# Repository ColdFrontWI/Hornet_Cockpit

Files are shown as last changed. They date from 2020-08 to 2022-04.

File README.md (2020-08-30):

# Eric's Hornet Cockpit file repository

A bunch of files I've created as part of designing and building a home cockpit for the F/A-18C.  Used in DCS playing in VR.

Folders here are:
* [**Pictures**](Pictures) is a good place to start as it includes writeups at several points in the history of
the build.  Part of that is a lot of pictures of the finished panel as well as the assembly process.
* [**DXF files**](DXF%20Files) contains CAD drawings that I used for the design of the side consoles and front panel, as well as
drawings used to construct the enclosures.  I created these in QCAD, but the drawings are in DXF format, so they should be
editable by most CAD tools.
* [**STL files**](STL%20Files) are the designs I created and used to 3D print various cockpit knobs and switches.  Having controls with the
right shape make things *much* easier in VR.  I'm not including gcode at this point as every printer is different, so you'll have to slice
these yourself.  I designed all of these in Fusion360, but I'm not including those files, mostly because Fusion360 is cloud-based, and it's
a pain to extract them to your machine.
* [**Arduino Code**](Arduino%20Code) are the programs I have written to drive the Arduino boards I use in my build.  While this is very specific
to my use cases, if you are new to Arduino coding this may provide some ideas.  [The Readme](Arduino%20Code/Readme.md) also includes
info about which boards work and a couple of code libraries that are likely to be needed.
* [**DCS lua code**](DCS%20lua%20code) are my customizations to the "default.lua" file that defines how cockpit controls work.  With some
modifications to the .lua code it is possible, for example, to make toggle switches send an action when turned OFF in addition to
when turned ON.  [The Readme](DCS%20lua%20code/Readme.md) explains the location of the files within the DCS install and provides guidance
on how to incorporate into DCS.
* [**Doc**](Doc) is NOT full documentation, but just a collection of files and links that I have collected and created for reference
along the way.

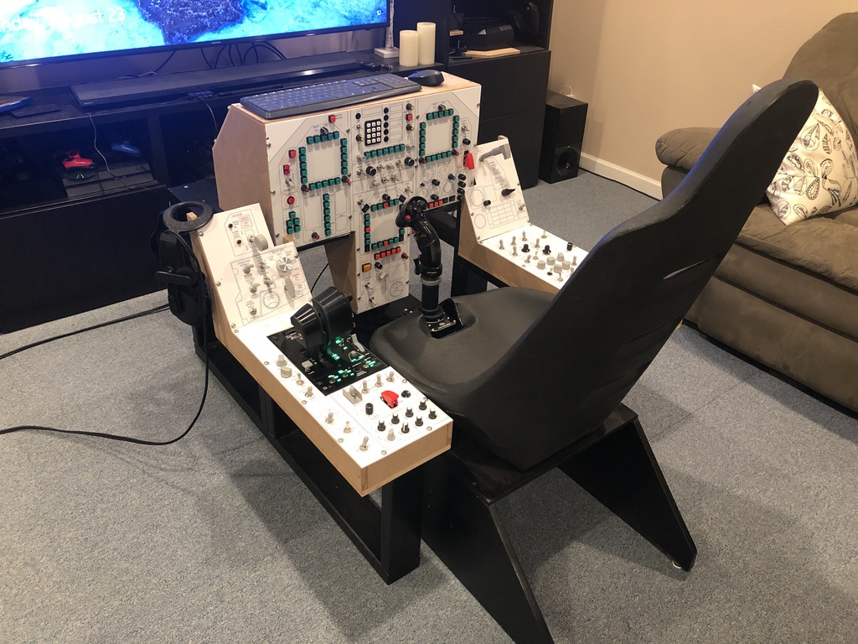
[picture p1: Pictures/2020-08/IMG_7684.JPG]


## License information

Shield: [][cc-by-sa]

This work is licensed under a
[Creative Commons Attribution-ShareAlike 4.0 International License][cc-by-sa].

[][cc-by-sa]

[cc-by-sa]: http://creativecommons.org/licenses/by-sa/4.0/
[cc-by-sa-image]: https://licensebuttons.net/l/by-sa/4.0/88x31.png
[cc-by-sa-shield]: https://img.shields.io/badge/License-CC%20BY--SA%204.0-lightgrey.svg

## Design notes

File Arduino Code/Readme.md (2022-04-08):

# Arduino code

When I started, I used the excellent [Leo Bodnar](http://www.leobodnar.com/shop/index.php?main_page=index&cPath=94&zenid=8e73e676aaff458fbce1cb81d2dc268f)
boards for my controls, but going forward I plan to use Arduino.  They provide a bit more flexibility, and
I find the coding fun.  My favorite "get started" resource is
[this video](https://www.youtube.com/watch?v=Z7Sc4MJ8RPM) which explains how to build a box using matrix wiring and
provides a link to [the code that drives it](https://github.com/AM-STUDIO/32-FUNCTION-BUTTON-BOX).  Just note that
if you use any latched switches like toggles in your design you'd want to add diodes to prevent ghosting.

## Which Arduino boards work?

The options may be broader if you plan to use DCSbios, but if you want to treat your Arduino as a USB_HID (like a joystick)
you will need one that uses the ATmega32U4 chip.  This includes the [Micro](https://store.arduino.cc/usa/arduino-micro)
and the [Leonardo](https://store.arduino.cc/usa/leonardo), but I have used
[these knockoff "Pro Micro" boards](https://www.amazon.com/gp/product/B07FXCTVQP/ref=ppx_yo_dt_b_search_asin_title?ie=UTF8&psc=1)
that can be had for <$20 for a pack of three on Amazon.

## Necessary libraries

There are two that I've used:
* [MHeironimus's joystick library](https://github.com/MHeironimus/ArduinoJoystickLibrary) is what allows Windows to see your
Arduino as a joystick.  You can set it up with up to 11 axes and 128 buttons.
* [brianlow's rotary encoder library](https://github.com/brianlow/Rotary) makes using encoders easy.

## My code

There are six  programs here:
* [**Supplemental_Controls.ino**](Supplemental_Controls.ino)
is what I use for the supplemental buttons I added to my cockpit to make things easier
to use in DCS in VR (bottom right of the front instrument panel, see picture).  Not part of the real aircraft, but I use it for things like
VR recenter, labels on/off, NVG goggles on/gain, and kneeboard management.  This also winds up picking up the slack from a few other places
where I didn't have ehough inputs.  This program includes code that reads a button matrix as well as rotary encoders.

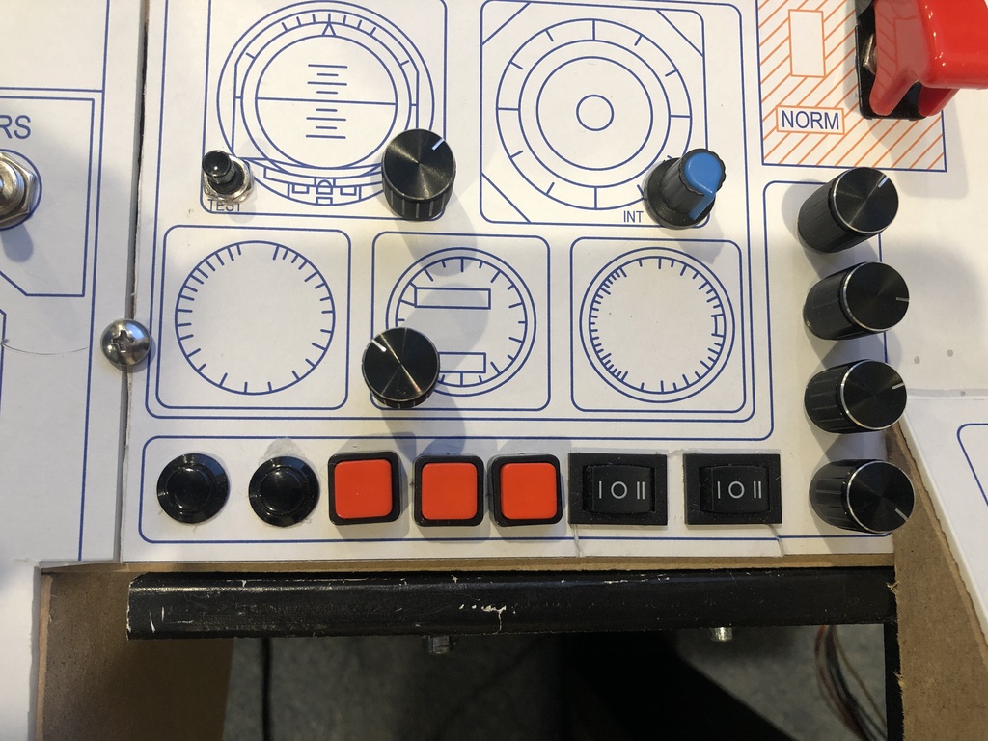
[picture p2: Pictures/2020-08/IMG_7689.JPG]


* [**AMPCD_CMS.ino**](AMPCD_CMS.ino) was created when I added the
APMCD to my build.  It is used for the bottom half of the HUD controls,
the APMCD, and the countermeasures panel.  Again, this includes a switch matrix and also has a couple of analog inputs.  With this program,
I figured out how to send joystick inputs both when a toggle is turned ON as well as when it is turned OFF.  I'm
in the process of editing this to remove some jitter on the analog inputs.

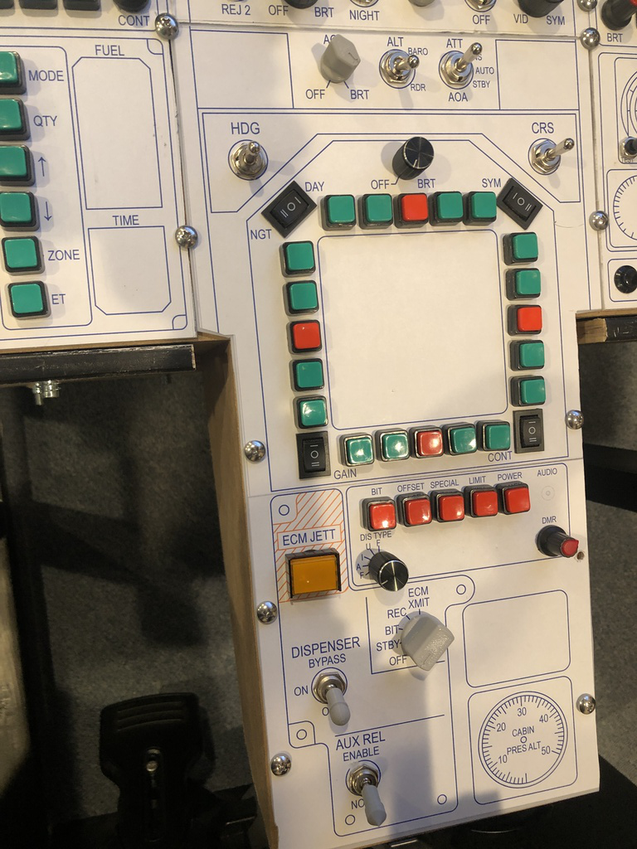
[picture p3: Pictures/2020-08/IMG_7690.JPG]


* Remaining programs control the left and right consoles.  For each console, I have one board for "switches" and one for "knobs" that
includes analog potentiometer inputs as well as rotary encoders.  There's a bit of code starting at line 245 in [Left_Panel_Switches.ino](Left_Panel_Switches.ino) that takes analog input from a potentiometer and converts it to button presses for the left/right
rotation of the hand brake.  (The push/pull is part of the regular button matrix.)  There is similar code in [Right_Panel_Switches.ino](Right_Panel_Switches.ino) for the wing fold handle.

## Next steps

Having replaced the side console Bodnar boards with Arduinos, I'm considering replacing some of the remaining front-panel controls
with them, but this seems a very low priority, as functionally things are working quite well.

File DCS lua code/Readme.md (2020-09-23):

# DCS .lua code

Two categories here:
* The "default\*.lua" files add custom entries in the control setup pages within DCS.  Can use these to make 
ON-OFF toggles work properly.
* "CMDS_ALE47.lua" replaces the default countermeasures programs with something I find more helpful.  Replace
the file found at *~\DCSWorld\Mods\aircraft\FA-18C\Cockpit\Scripts\TEWS\device* with this version.

# Using toggle switches in DCS

Toggle switches present a challenge when building any kind of button box.  While they send an input when you
turn the toggle "on," they don't provide any kind of signal when you turn the toggle "off."  There are some
ways around this:
* You can use ON-ON toggles rather than ON-OFF, but that takes up twice as many inputs on your interface board.
* You can write Arduino code that will send an output not only when a toggle is switched ON, but also when it's switched OFF.
Examples of this type of coding can be found in
[this program](https://github.com/ColdFrontWI/Hornet_Cockpit/blob/master/Arduino%20Code/05_Hornet_AMPCD_CMS.ino) in the
[Arduino Code](https://github.com/ColdFrontWI/Hornet_Cockpit/tree/master/Arduino%20Code) folder.

Fortunately, DCS offers a way to handle this by adding custom controls to an aircraft's control setup menu.  These are
sored in the "default.lua" file.  And some of these types of controls may already be set up:
* In the A-10C, all of the toggles on the TM Warthog throttle work out of the box
* On the Hornet, ED has added appropriate functionality for all of the three-way ON-OFF-ON toggles in the cockpit and a
selection of the two-way ON-OFF toggles.  But many of the ON-OFF toggles will require you to add your own custom controls.

You should be able to add any of the "default - *Aircraft* append.lua" files in this folder, to the "default.lua"
file for the relevant plane, and additional options will show up in the DCS control setup.  Just be sure to take
note of *where* you add the append file.  This is noted in comments of the Hornet version of the file, but I put it
right after the
~~~
join(res.keyCommands,{
~~~
line in default.lua.  Once you edit
default.lua you will see some additional control groups in the setup page (see picture below).
You can then bind them to whichever switch you want.  For reference, the Hornet's default.lua file is located at
*~\DCSWorld\Mods\aircraft\FA-18C\Input\FA-18C\joystick* within the DCS installation.
  
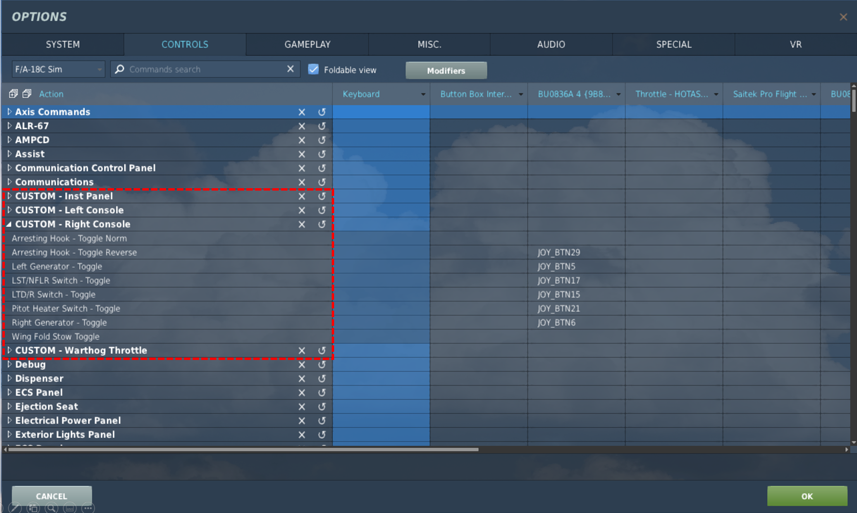
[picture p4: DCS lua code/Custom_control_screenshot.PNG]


## Other notes
* For my cockpit, I set some of the controls up in "reverse" for various reasons.  For example, the toggle I
use for the arresting hook is "on" in the down position rather than up.  If you find some of my custom controls
work in reverse, you can edit it to suit your needs.
* Some switches in the real cockpits are electronically held, so they can automatically be switched off.  Anti-skid
in the Warthog, and LTD/R ARM in the Hornet are examples.  These often have a different value for the "OFF" position
than other switches, so if one is not working you may need to edit.
* Recommend you keep a copy of your "append" file around separate from the main default.lua.  DCS updates occasionally
overwirte default.lua, and if you don't have the append file you'll have to rewrite from scratch.  Ask me how I know ;).

## Other aircraft

Obviously not relevant for the Hornet, but I'm also including the files I set up for the Warthog and the Mustang here.

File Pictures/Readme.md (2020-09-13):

# Pictures

As I have reached major milestones in the build, I have taken some pictures, and have done a brief
writeup of where the project was at that point.

* [**February 2020:**](2020-02/Readme.md) This shows the frame I had built several years ago that all of the
Hornet cockpit mods are attached to.
* [**April 2020:**](2020-04/Readme.md) I had the side consoles built at this point.
* [**May 2020:**](2020-05/Readme.md) Had the side consoles and the original version of the instrument panel built.
This page includes a lot of "behind the scenes" pictures and detail about how each panel was assembled.
* [**August 2020:**](2020-08/Readme.md) Pictures after modifying it to include the AMPCD, as well as adding
bunch of custom-designed, 3D-printed knobs and switches.
* [**September 2020:**](2020-09/Readme.md) A couple of new controls added, a few more 3d printed knobs, and swapping
out the Bodnar boards on the left and right consoles for Arduinos to allow more inputs.



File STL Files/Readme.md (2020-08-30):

# 3D printer files

* [**Knobs**](Knobs): Designed to be used on rotational controllers (potentiometers, rotary encoders, rotary switches).  All fit 6mm splined shafts unless otherwise noted.
* [**Switches**](Switches): Designed to be glued over "standard" bat-style toggle switches.  All have 6mm openings to accomodate the switch.
* [**Other**](Other): Holder for other parts that I've created along the way that may or may not be part of the design.

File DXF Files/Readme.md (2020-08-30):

# DXF Files

Two subfolders here:
* [**Panel**](Panel): This is the detailed switch layout.
* [**Enclosure**](Enclosure): How I built the boxes.

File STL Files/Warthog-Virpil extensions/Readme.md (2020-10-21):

# Warthog / Virpil stick extensions

**Update:** I had a couple of these crack at the male threads after some use when printed using typical settings (2 layer side walls, 20% infill).  So I printed one solid (100% infill), and it's been going strong for a while now.

I had a 75mm extension that I was using with my Virpil WarBRD base and Thrustmaster Hornet grip, but I found that
my setup really needed a 50mm.  I wasn't too keen on spending >$50 (with shipping) and waiting until one was in
stock from Virpil or another supplier, so I decided to design and 3D print my own.  The 50mm design was well-received
when I shared it, and one person requested a different length so I made several between 25 and 100mm.

Note there are three versions of each.  I found that the 36mm female thread on these designs was VERY tight
and difficult to install on my setup, so I created versions where the female threads are 36.5 and 37.0mm.
I think my issue with the 36.0mm may be my printer being slightly out of square, but the 36.5 and 37.0
fit nicely.  You may need to experiment to find out which gives the best fit with your setup.

### 50mm design side-by-side with a 75mm from Virpil

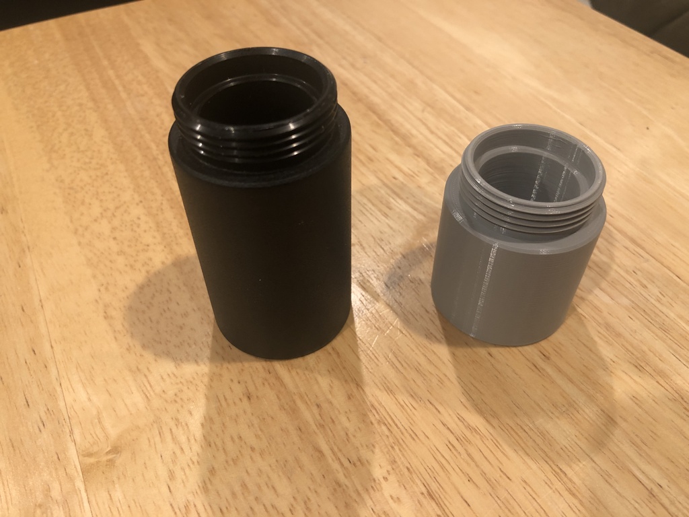
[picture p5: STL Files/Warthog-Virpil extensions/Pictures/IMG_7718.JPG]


### The female threads

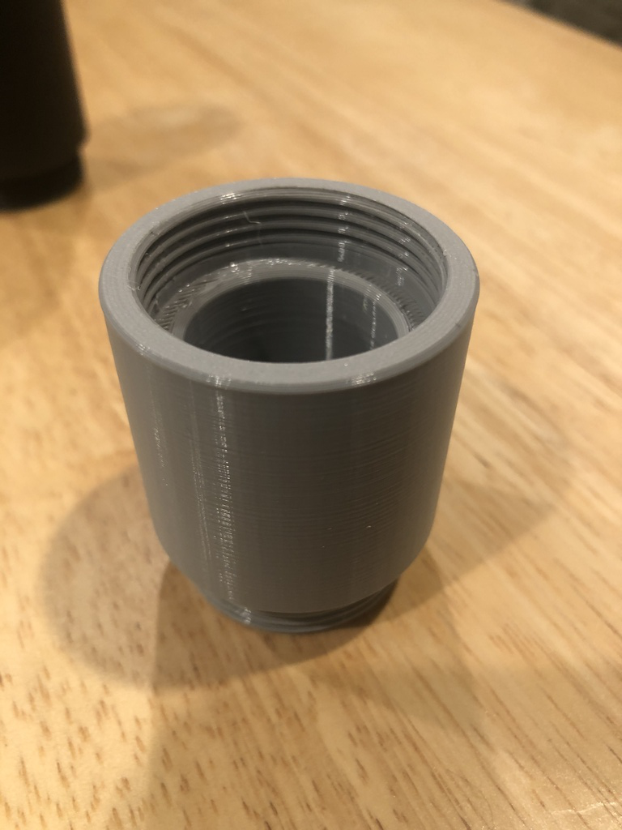
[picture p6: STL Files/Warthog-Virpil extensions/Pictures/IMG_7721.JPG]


### Installed between WarBRD base and TM Hornet grip

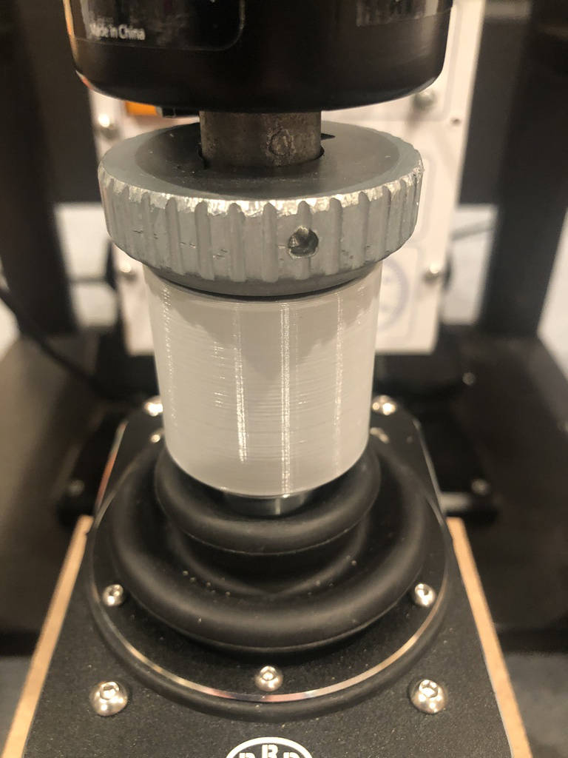
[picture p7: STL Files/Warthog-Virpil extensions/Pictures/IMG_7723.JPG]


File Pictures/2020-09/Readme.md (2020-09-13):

# A few key functional updates

Not many new pictures at this point, but some pretty nice updates.  First, I've added a couple of new
controls.
* I installed [blue73's Jettison Control](https://forums.eagle.ru/showthread.php?t=239718), replacing
the rotary encoder that was there before.  This thing is awesome!
* I changed the hand brake mechanism.  I previously had a pushbutton rotary encoder here, but replaced it with
a push-pull potentiometer, and designed a collar to ensure it moves in a way that's consistent
with the movements in the plane.  This was inspired by [TekCreations use of a push-pull
pot.](https://www.tekcreations.space/f18-landing-panel-part-2/?v=7516fd43adaa)  The STL files
for the collar, the shaft, and the top handle can be found in [the STL files
section.](../../STL%20Files/Other)
* I also swapped the encoders being used for the Radar and INS for proper rotary switches.  Previously it was
way too easy to accidentally bump the INS when using the targeting pod switches.

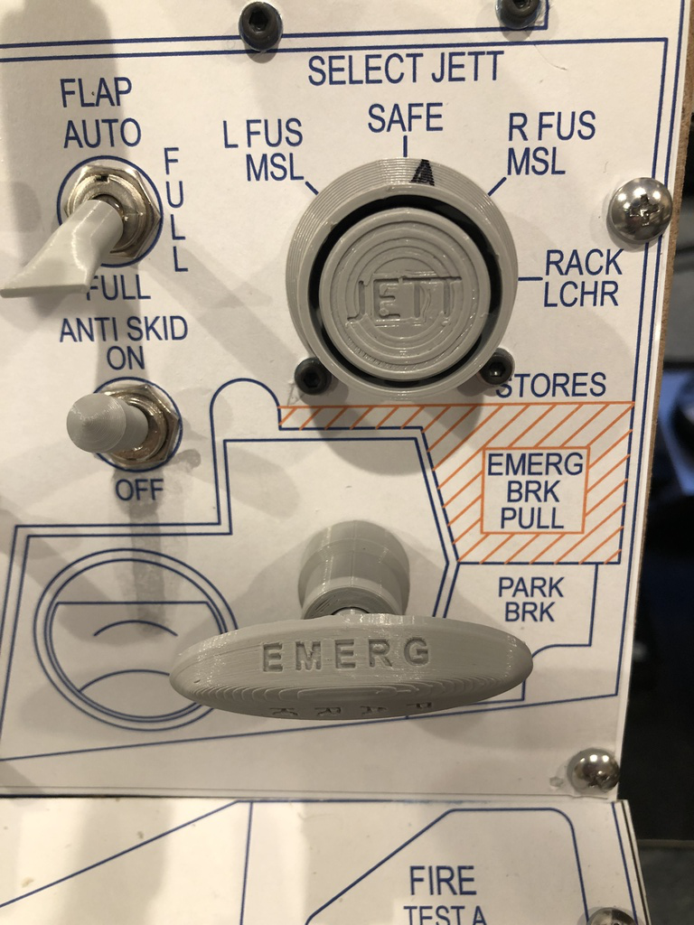
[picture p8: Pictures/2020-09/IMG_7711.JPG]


Those controls were enabled by the biggest change: Swapping out the Bodnar boards on the left
and right consoles for Arduinos.  I wound up using two knock-off Pro Micros in each side (one for switches
and one for analog inpugs and encoders), but this provides a number of nice features:
* **More inputs:** The Bodnar boards I had were limited to 36 digital inputs, and I ran out of inputs
and had to run wires for a couple of things main panel.  This is no longer
necessary.  In the end I have ~50 unique buttons on each side.
* **Send button on both on and off:** I wrote the code so that it sends a joystick button both when a
switch is turned on as well as when it is turned off.  So even though many of my switches are on/off
(e.g. landing gear), it can send a joystick button push in both directions.

I also 3D printed some more knobs including the Bleed Air and Cabin/Suit temp as a rudder trim knob.
For the temp knob, I used a stacked concentric potentiometer...because you know, it's important to
be able to turn those knobs in the cockpit! ;)

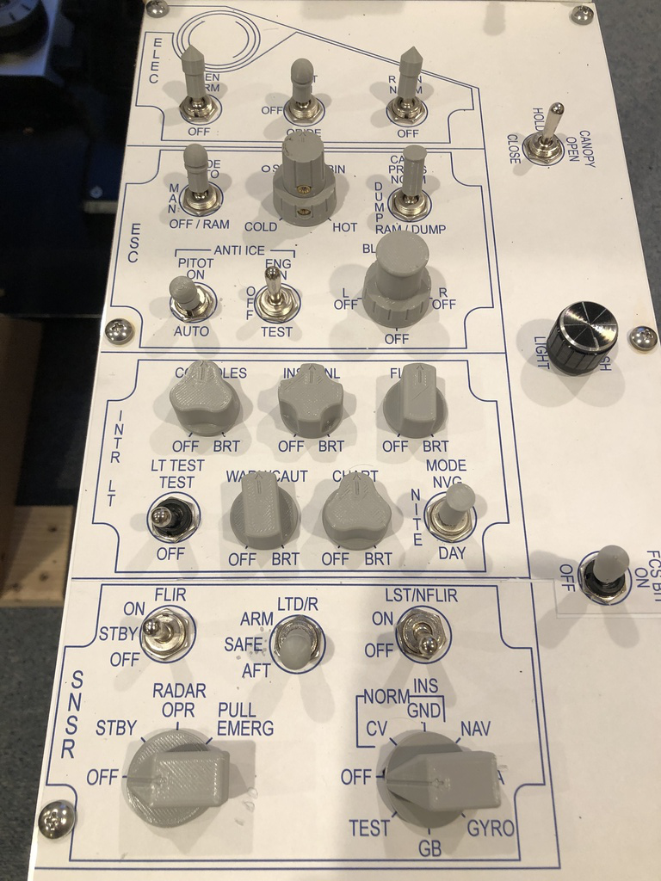
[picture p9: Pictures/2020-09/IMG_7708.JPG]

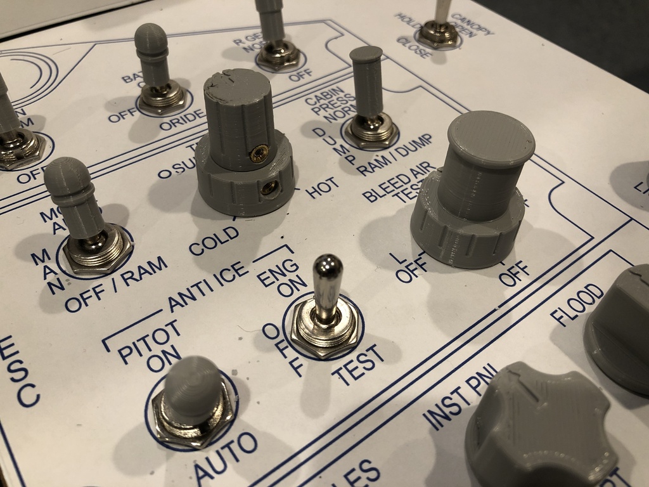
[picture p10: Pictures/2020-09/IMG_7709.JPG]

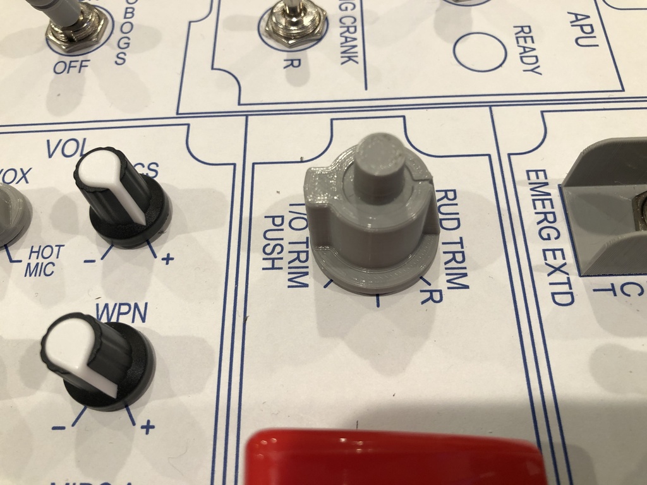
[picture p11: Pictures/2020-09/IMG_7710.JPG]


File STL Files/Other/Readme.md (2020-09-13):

# Other

Random other STL files that I've found or created along the way.  A couple that are here:

* [**Button adapter.stl**](Button%20adapter.stl) and [**Multiselector gear 18t.stl**](Multiselector%20gear%2018t.stl)
are modifications to [blue73's awesome Jettison Select Knob](https://forums.eagle.ru/showthread.php?t=239718)
that allow me to use parts I had on hand including the pushbutton and rotary.  I [posted these to the ED
forums](https://forums.eagle.ru/showpost.php?p=4471487&postcount=58).
* [**Panel - lower LG.stl**](Panel%20-%20lower%20LG.stl) is something I created as a quick test to see if I
could 3D print overlays for my panel to give it a bit more depth.
* When used in conjunction with a push-pull potentiometer, the **"Hand brake"** files create a mechanism
which mirrors the parking / emergency brake in the Hornet.

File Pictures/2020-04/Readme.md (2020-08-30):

# The side consoles

By April, 2020 I had the two side consoles built.  The left side was designed to fit a Warthog throttle.  Also, I don't know if this
is reality, but based on the time I spent sitting in the Hornet DCS cockpit in VR I designed it so the left vertical panel (gear,
etc.) is closer to the pilot than the right side vertical panel (wing fold, arresting hook, etc.), so I built it that way.

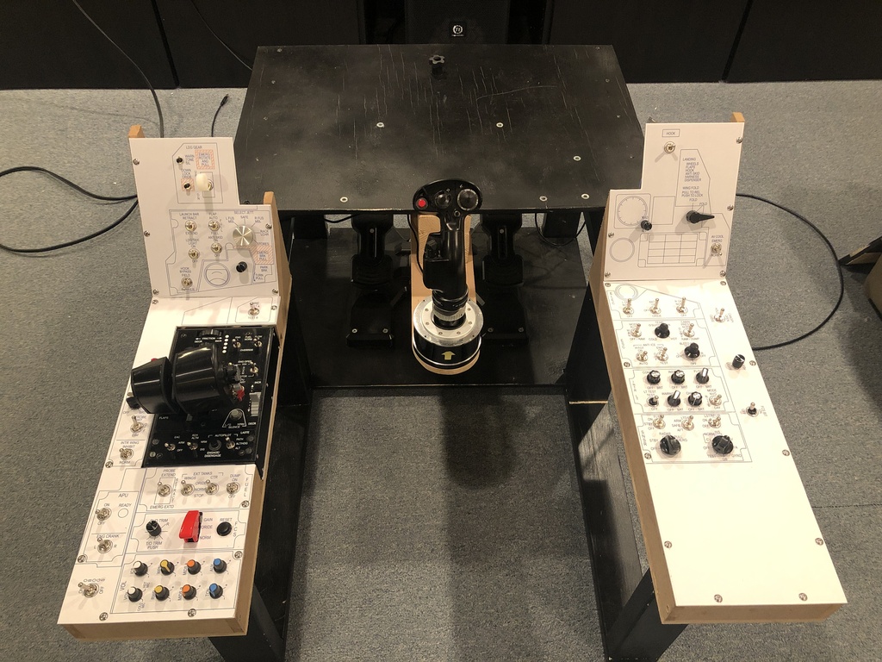
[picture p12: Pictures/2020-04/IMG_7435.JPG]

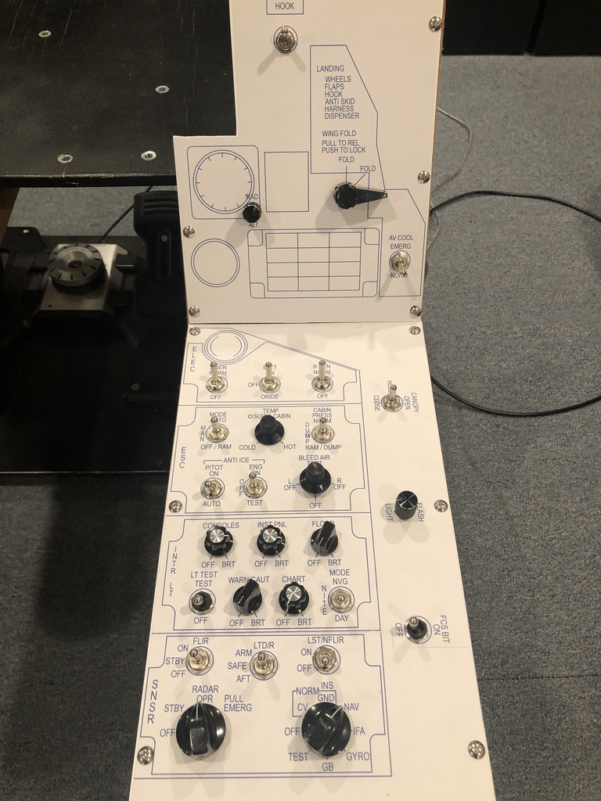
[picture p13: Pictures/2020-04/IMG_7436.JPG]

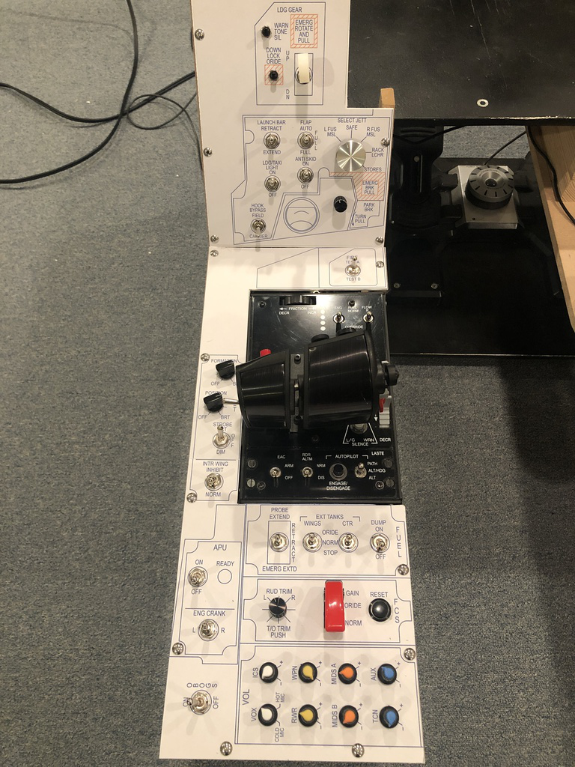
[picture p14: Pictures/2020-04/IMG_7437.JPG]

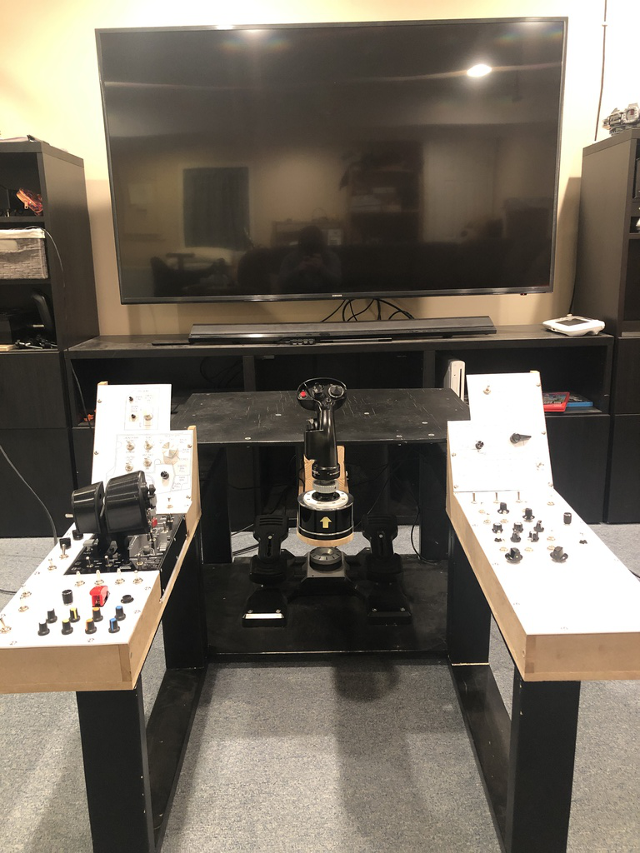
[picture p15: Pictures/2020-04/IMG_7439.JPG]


And as of now it still fits neatly in the corner.

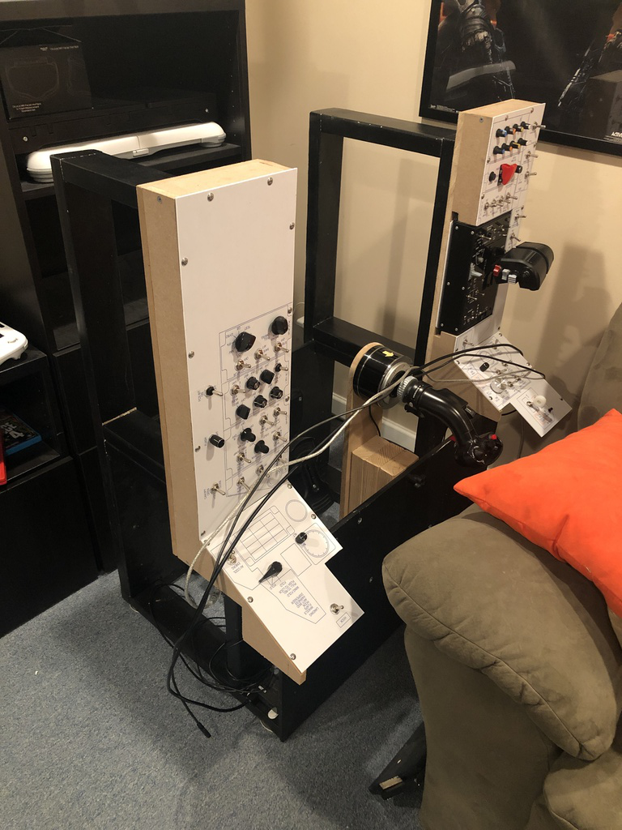
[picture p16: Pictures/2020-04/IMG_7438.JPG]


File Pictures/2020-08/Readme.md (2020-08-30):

# An AMPCD and some fancy knobs

I was really enjoying the design as it existed, but I did find a couple of problems that made it a challenging in VR:
* Some switches and knobs were hard to identify.  I had bought a few knobs that kind of mirrored the shapes in the actual cockpit,
but some were impossible to find.  I also had no way to differentiate toggles, which meant a lot of counting by feel to figure
out which switch I needed to use.
* I got so used to using my panels that I would often reach for the OSBs on the AMPCD, but...I didn't have an AMPCD!  So I would then have
to feel around for my mouse to work with the AMPCD.

## Knobs and switches

To help with identification of controls in VR, I picked up a [Creality Ender 3 Pro 3D printer](https://www.amazon.com/gp/product/B07K3SZBHJ)
and designed a bunch of custom [knobs](../../STL%20Files/Knobs) and [switch caps](../../STL%20Files/Switches).  There is a bit
more detailed information on the designs in the readme files in those locations.

### Knobs

A few custom shapes for various potentiometer and rotary switches in the cockpit, including the parking brake
handle.  For the most part I have made these to fit over splined 6mm shafts.  All of the designs are over in
the [STL Files section](../../STL%20Files/Knobs).  I have made a few more since the pictures below.

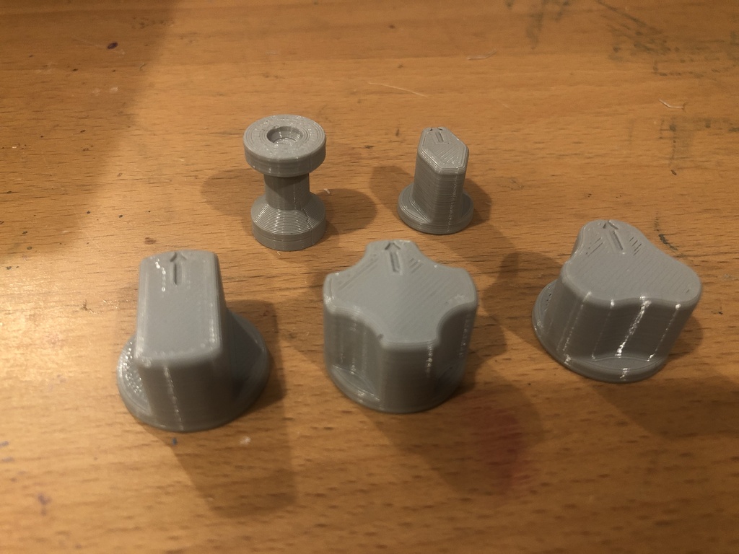
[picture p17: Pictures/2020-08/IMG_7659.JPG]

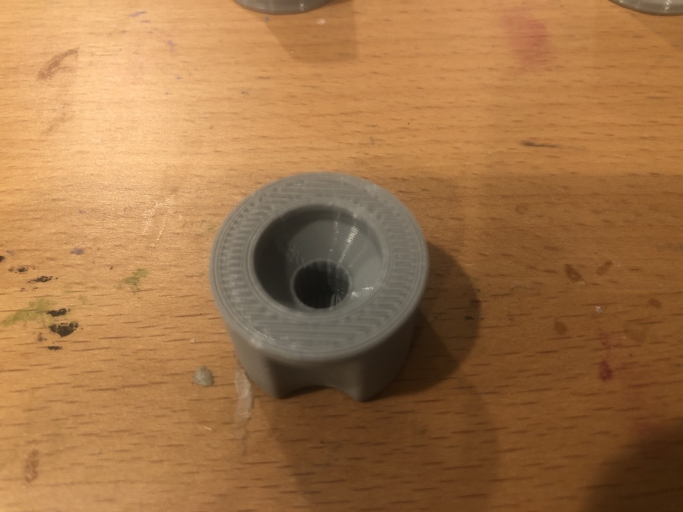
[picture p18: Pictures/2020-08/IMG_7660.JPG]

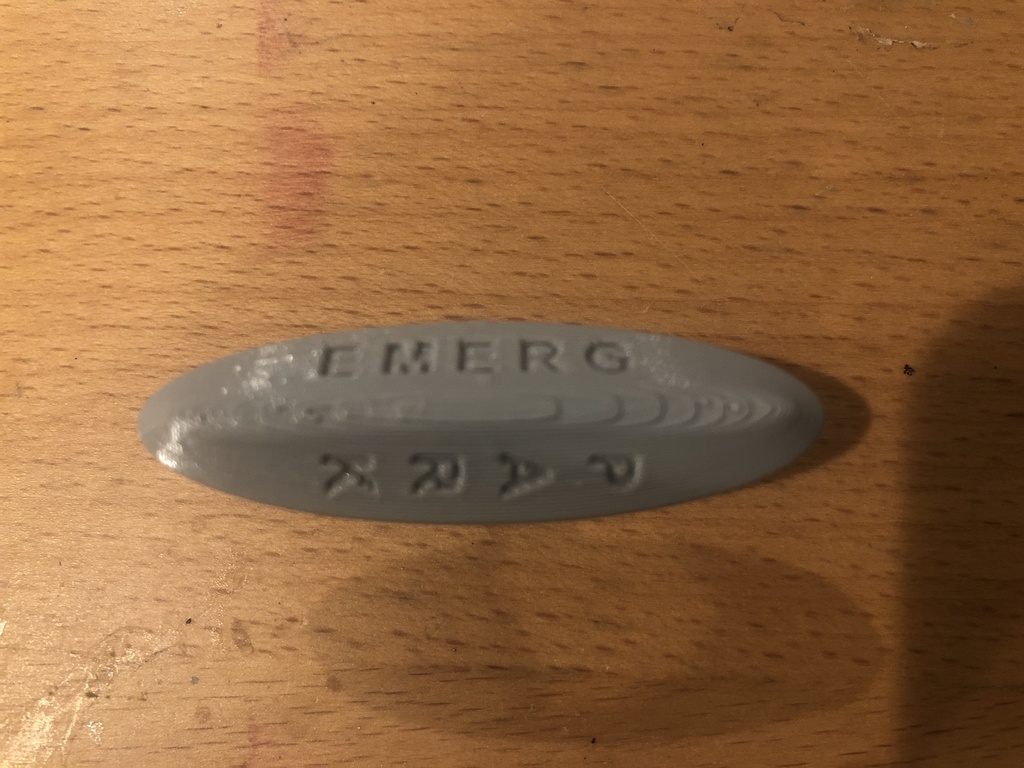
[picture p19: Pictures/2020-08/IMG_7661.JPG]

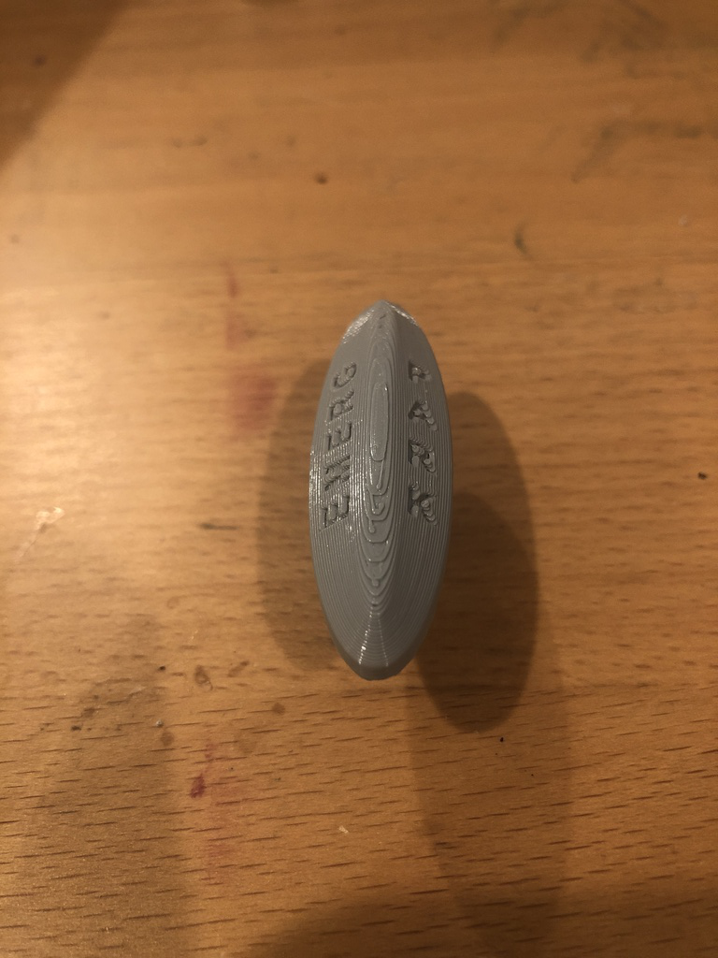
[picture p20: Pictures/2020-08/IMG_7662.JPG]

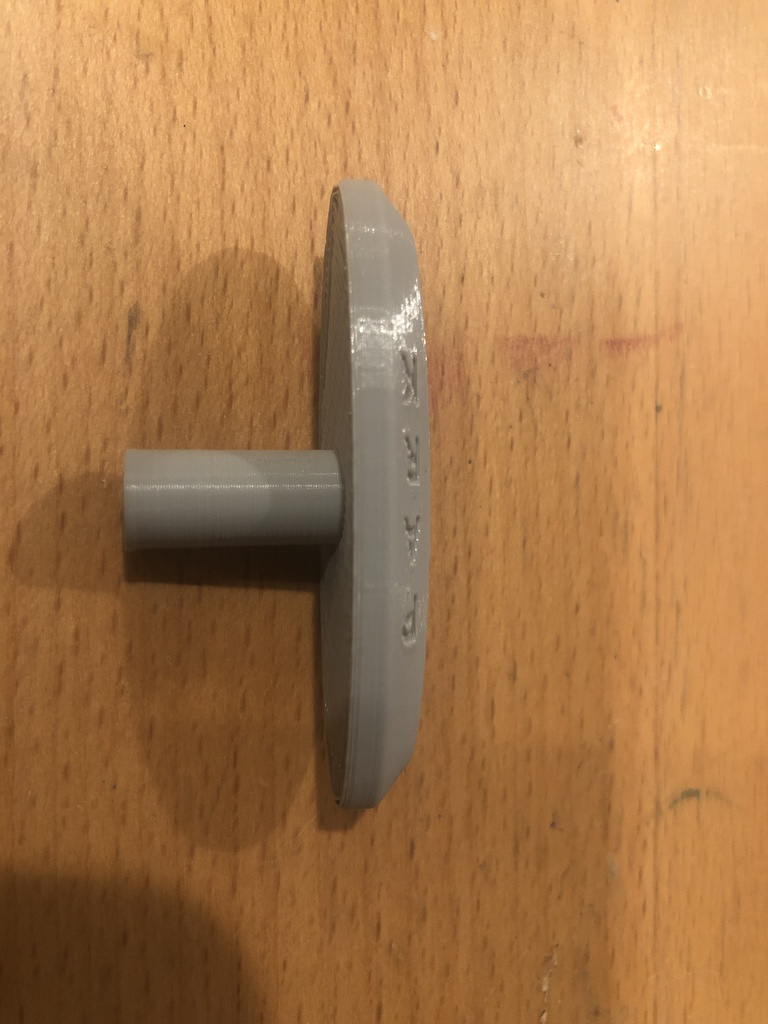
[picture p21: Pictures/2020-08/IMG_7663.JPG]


### Basic switch caps

The Hornet seems to have three "non-standard" switches that are used in several places in the cockpit including
one with a pointy top, one with a dome, and one with a flat top.  In addition, there are unique switches for the
flaps, the launch bar, and the landing/taxi lights.  All of the designs below are in the [STL Files
section](../../STL%20Files/Switches).

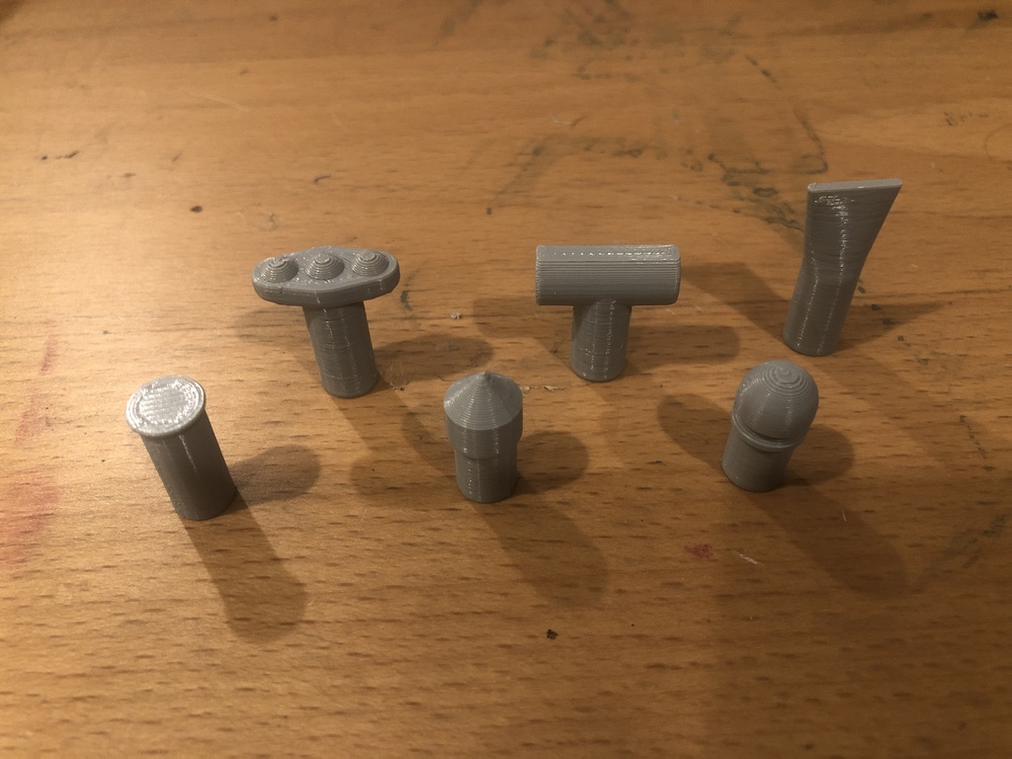
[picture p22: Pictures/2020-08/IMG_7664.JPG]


### Lever handles

My design uses toggles for the landing gear and arresting hook controls, so I printed handles for those as well.

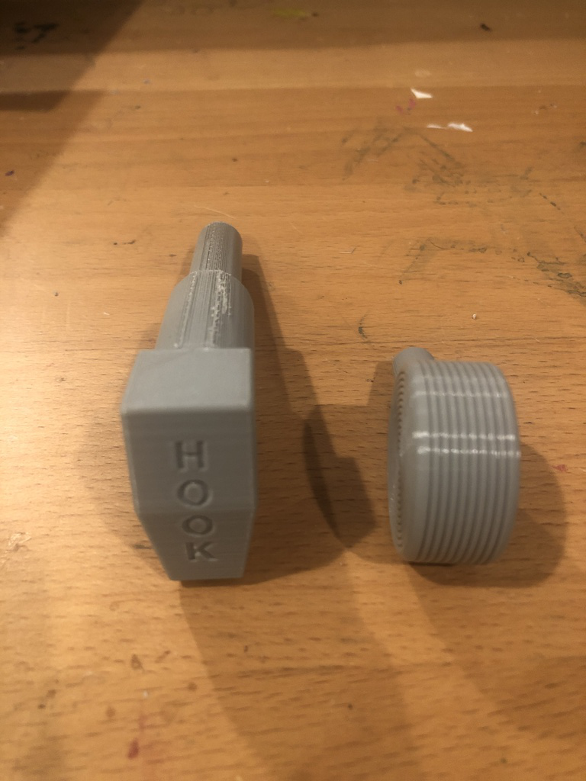
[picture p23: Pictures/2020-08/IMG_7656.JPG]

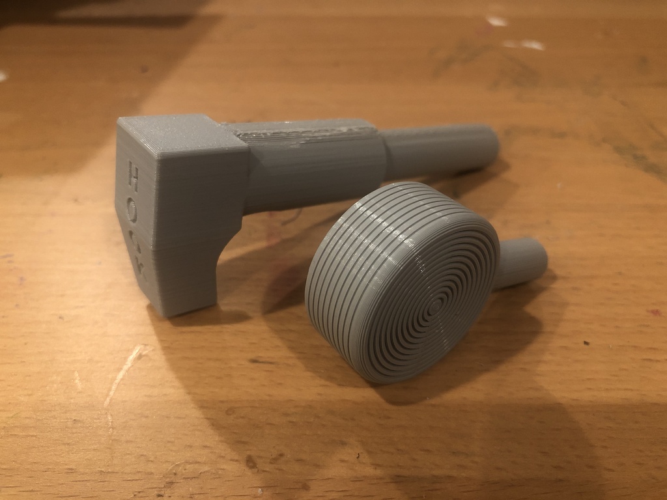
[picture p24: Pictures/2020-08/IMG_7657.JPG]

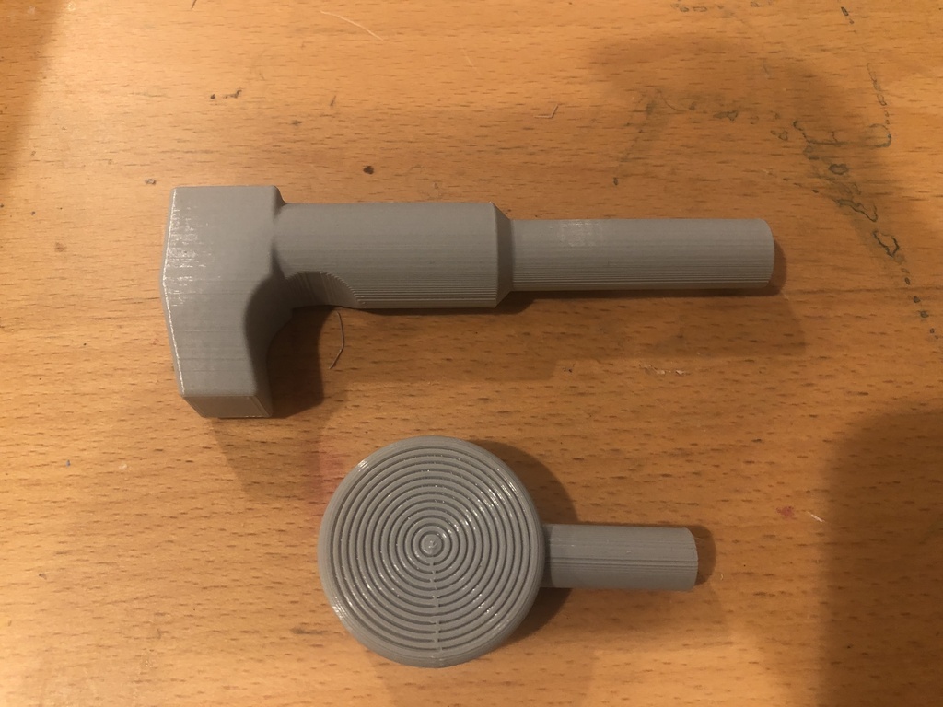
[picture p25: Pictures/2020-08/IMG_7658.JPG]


## The AMPCD

To make this modification, I had to cut away some of the existing insturument panel to fit the replacement.
I also had to change the way my stick was mounted.  Timing here was convenient, as I had recently received my Virpil
WarBRD base to replace my trusty if somewhat sticky TM Warthog.  I also had to add an additional [Arduino-compatible
Pro Micro control board](https://www.amazon.com/gp/product/B07FXCTVQP) to drive the additional switches and buttons.



## Putting it together

With the AMPCD, the Virpil bsae, and all the custom switches and knobs, this setup is a blast to fly with and really
easy to use in VR.  And it even still fits in the corner!













## Next steps

There are of course already a few things I'm contemplating.
* I want to replace some of the rotary encoders with proper rotary switches, specifically the INS, Radar, and Jettison
select knob.  For the Jettison select knob/button, I plan to use [blue73's excellent design from the ED
forums](https://forums.eagle.ru/showthread.php?t=239718), see picture below.  I'm also going to try swapping out the
parking brake rotary encoder for a push/pull potentiometer as [TekCreations describes on their Hornet panel design
page](https://www.tekcreations.space/f18-landing-panel-part-2/?v=7516fd43adaa).
* To make the changes above, I will probably rewire the left and right consoles with Arduino-based boards.
* I want to add the countermeasures "slap button."  My pit doesn't have a side wall, so I'll probably just put it
somewhere on left console panel.
* I want look at swapping many of the pushuttons (e.g. all of the OSBs on the three displays) for tactile switches, and
print custom keycaps.



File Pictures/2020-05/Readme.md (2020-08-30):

# The cockpit is...done?

## Enclosures

The enclosures were built from MDF and screwed together.  The sides are 1/2" thick and the top/bottom (and back
of the front panel) are 1/4".  CAD files for the design for the framing pieces are located in the [DXF
Files/Enclosure folder](../../DXF%20Files/Enclosure).






## Panels / Wiring

The panels themselves are [1/8" white acrylic that I picked up from
Amazon](https://www.amazon.com/gp/product/B06XNXHZZH).
For the markings, I inkjet printed onto [full sheet
labels](https://www.amazon.com/gp/product/B074KQRJKN).
Because the panels are smaller than the labels, I had to trim and fit them together.  The CAD files that
make up the panel design are located in the [DXF Files folder](../../DXF%20Files/Panel).  One of the key
features of the panel design are hole center marks to help with drilling and cutting the holes
necessay for all the buttons/switches/knobs.

For control boards, I used several of the [Leo Bodnar](http://www.leobodnar.com/shop/index.php?main_page=index&cPath=94)
boards including four [BU0836A boards](http://www.leobodnar.com/shop/index.php?main_page=product_info&cPath=94&products_id=204)
combined with [Matrix Breakout boards](http://www.leobodnar.com/shop/index.php?main_page=product_info&cPath=94&products_id=274)
as well as one [BBI-64](http://www.leobodnar.com/shop/index.php?main_page=product_info&cPath=94&products_id=300).

This design also includes one [Arduino knockoff "Pro Micro"
board](https://www.amazon.com/gp/product/B07FXCTVQP) for the "supplemental"
switches at the bottom right of the front panel.  This particular
board can be set up to behave like a USB HID, so DCS sees it as a game controller.  The Bodnar boards are great, but with
Arduino I can do things like setting an on-off toggle to send a joystick button press when the switch is either turned
on *or* off which helps avoid some .lua code in the setup.

### Side consoles

Each uses a Bodnar BU0836A plus a Matrix breakout board, and the eft side is designed to fit around the the Warthog Throttle. 

#### Left side






#### Right side






###  Instrument panel

Built on a single piece of acrylic using four control boards including two Bodnar BU0836As and a Bodnar BBI-64.  The bottom
right supplemental buttons use an Arduino-compatible Pro Micro board.



#### Left





#### Center





#### Right

On the Bodnar board on this side, I skipped the breakout board for the BU0836A and wired the matrix myself directly
including the diodes needed to avoid ghosting.  I learned that it's actually much easier to wire this way, and results in
a lot less spaghetti.







#### Instrument panel assembled

I'm pretty happy with the way it came together.  I added a [13-port powered USB
Hub](https://www.amazon.com/gp/product/B00HL7Z46K/ref=ppx_yo_dt_b_search_asin_title?ie=UTF8&psc=1)
so I only need to connect one wire to my PC.  Well, actually two...in order for all devices to be recognized I also
need to provide external power to the hub.






## Looking good

Overall, I'm very happy with how this turned out.  It's easy to connect/disconnect, easy to move out of the way in the room, and
it's pretty easy to find the controls, even in VR.  It even still fits in the corner, although I did have to move the couch a couple of inches.





## So I'm done now, right?

Not so fast!  As you I can see, I left off the AMPCD--this was due to way the stick was mounted.  The problem was that I kept reaching for
the AMPCD in VR.  So the next major phase was modifying to add the AMPCD...

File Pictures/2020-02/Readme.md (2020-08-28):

# A bit of history

The core of this home pit dates back well before the Hornet.  It started out as a flexible/modular system on which I
could easily swap controls between a yoke/civilian throttle quadrant and my t Flight HOTAS at the time.  It also had
to easily slide out of the way and fit in a corner of the basement, which this does nicely.

I first built this back ~2017 when I got back into flight sims after a multi-decade hiatus.  I expected to play mostly
XPlane/MSFX (thus the yoke), but then I found WarThunder--and then Elite Dangerous--and racked up several hundred hours in each.

And then I found DCS and the time sink/spending
really increased.  I got a TM Warthog and built a simple switch box for the A-10C module that had some of the key controls
including all the arming switches, gear, etc.  That's about where this was back in Feb before I got started on the
Hornet pit.

## Configured for military flight sim
The stick is on an extension arm built from 2x4s that attaches to the underside of the table.  The button box on the left
is something I built for flying the Warthog in VR in DCS.  It has some of the most-used switches including the landing
gear as well as most of the arming panel.




## Configured for civilian flight sim
I added a plywood base to the yoke and the throttle quadrant with holes drilled so I could use hand screws to quickly
attach it to or remove it from the base.




## Side conveniently out of the way
I stuck furniture sliders on the "front" of the pit so when I stand it up on it's end it will slide easily.  It's easy
to move it out of the way and slide it into the corner.



## The seat
Since I've been asked a couple of times, the seat here is basically a [kart racing seat that I found on
Amazon](https://www.amazon.com/gp/product/B007VRCTD6/ref=ppx_yo_dt_b_search_asin_title?ie=UTF8&psc=1) and mounted on
a DIY base.  Don't know if Amazon still carries it, but you can probably go directly to JEGS.



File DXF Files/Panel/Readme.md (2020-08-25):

# Panel Layout

This is the full panel that I used for construction.  This was drawn in QCAD using several sources:
* The NATOPS manual foldout.  I created the image files in the ./Bitmap subfolder, inserted them into QCAD,
scaled them to the appropriate size, and then used them for reference.  Some things were intentionally
drawn smaller to make things fit, notably the three displays.
* To get the scaling right, I used the dimensions provided for a few of the panels available
from [PC Flights](http://pcflights.com/index.php?main_page=index&cPath=47_70).
* Building a cardboard mockup, sticking printouts to it, and sitting in a chair for a long time pulling
my VR headset on and off to see how things fit together.

Couple of comments on the main DXF file:
* There are a lot of layers here that I used to visualize, but turned off all but CutTier1, EmergHatch,
SwCenter, SwDrill, SwitchTier1, and TextTier1 to print.
* The bitmaps are in the DXF, but they reference an absolute path on my PC.  If you want them to show up,
open the DXF in a text editor, find the instances of .png, and replace all of the path information with
whatever is appropriate for your setup.
* On the bottom right of the front panel below and to the right of the "steam gauges" are a few buttons
that are not Hornet specific.  I use them for things like recentering VR, opening and moving around
in my checklists, slowing down/speeding up time, etc.

In terms of the actual construction, it was fairly straightforward:
* Cut the acrylic to size
* Print the panels at 1:1 on [full-sheet labels](https://www.amazon.com/gp/product/B074KQRJKN/ref=ppx_yo_dt_b_search_asin_title?ie=UTF8&psc=1).
Obviously it doesn't all fit on one sheet, so I had to cut them carefully, and fit them together
* Cut/drill the holes needed for your switches.  The SwCenter and and SwDrill layers in the DXF help with this.
* Install the switches and wire it up!

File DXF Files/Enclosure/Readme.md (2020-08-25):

# Enclosures

This shows how the left, right, and front consoles were built.  There are files that show the shapes that need to be
cut for each of the three encosures, as well as the acrylic pieces.  I built the enclosures out of a mix of 1/4"
and 1/2" MDF that I picked up at Home Depot.  The panel faces are [1/8" white acrylic I picked up from
Amazon](https://www.amazon.com/gp/product/B06XNXHZZH/ref=ppx_yo_dt_b_search_asin_title?ie=UTF8&psc=1).

Note that the front console was actually built in two steps...I first built the rectangular box that did
not include the AMPCD (the "MDF - Front Panel...") files.  I had to modify it later when I added the AMPCD
("Acrylic-MDF - AMPCD replacement...")

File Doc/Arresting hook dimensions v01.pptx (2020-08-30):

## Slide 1

No photo description available.

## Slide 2

No photo description available.

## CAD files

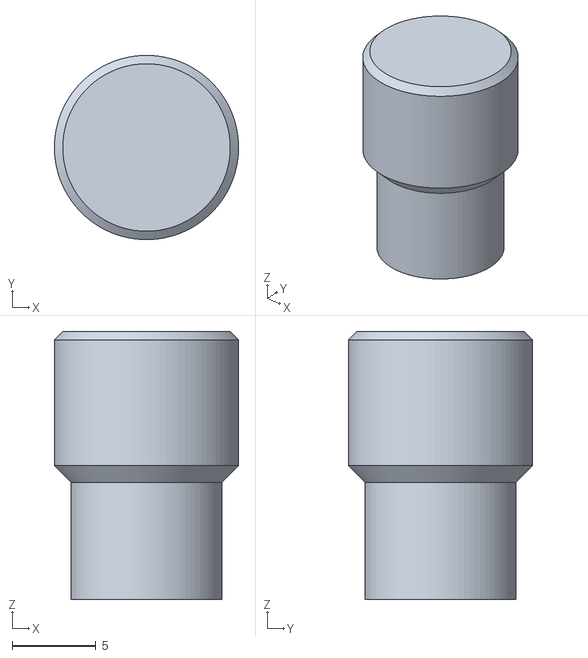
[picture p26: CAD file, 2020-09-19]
STL Files/Knobs/Tiny knob.stl
11.0 x 11.0 x 16.0

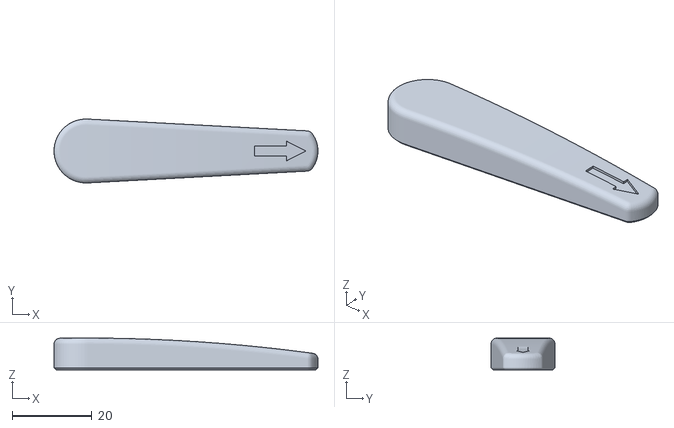
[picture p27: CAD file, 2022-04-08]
STL Files/Other/Wing fold handle.stl
66.0 x 16.0 x 8.00

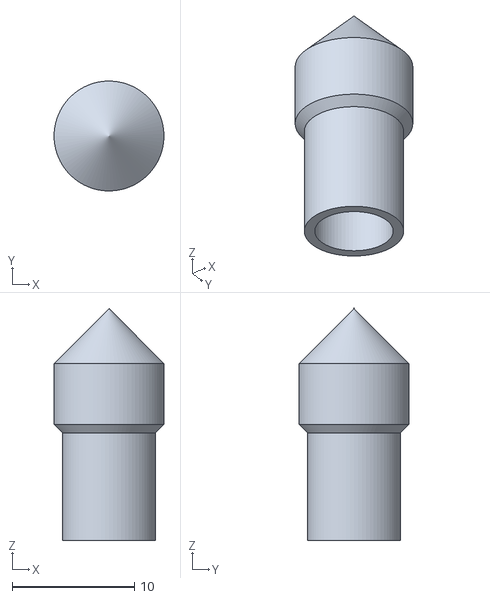
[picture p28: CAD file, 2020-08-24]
STL Files/Switches/Sw - Pointy.stl
9.00 x 9.00 x 19.0

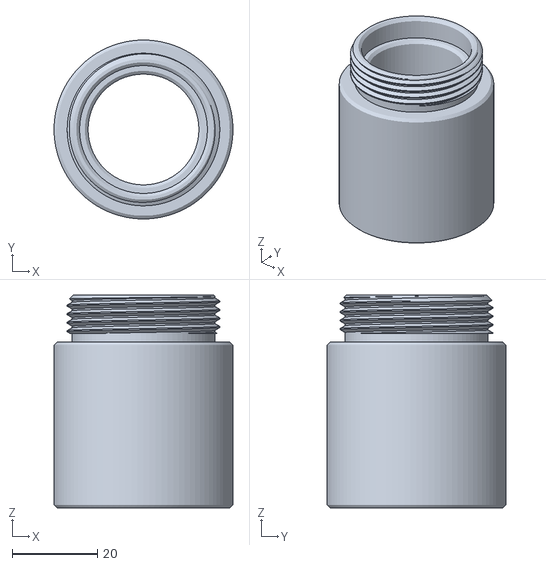
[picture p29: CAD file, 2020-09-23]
STL Files/Warthog-Virpil extensions/WH ext 50mm, 36.5.stl
42.0 x 42.0 x 50.0

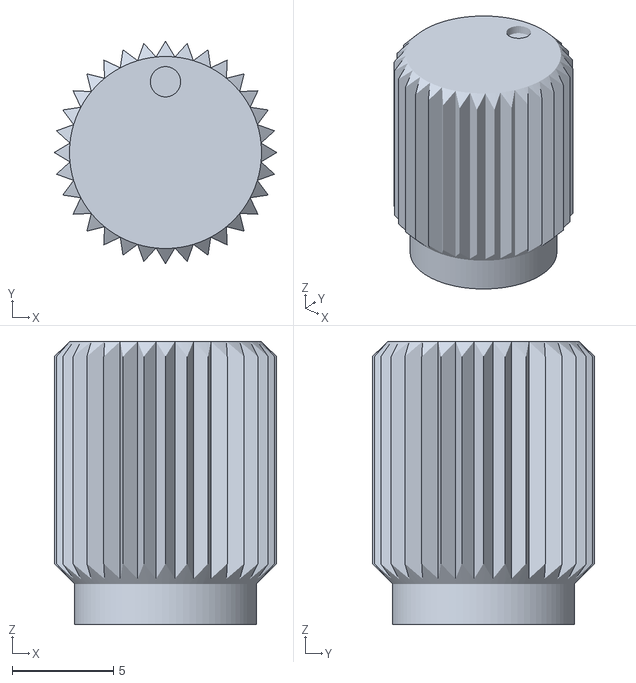
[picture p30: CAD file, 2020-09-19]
STL Files/Knobs/Small knurled knob.stl
11.0 x 11.0 x 14.0

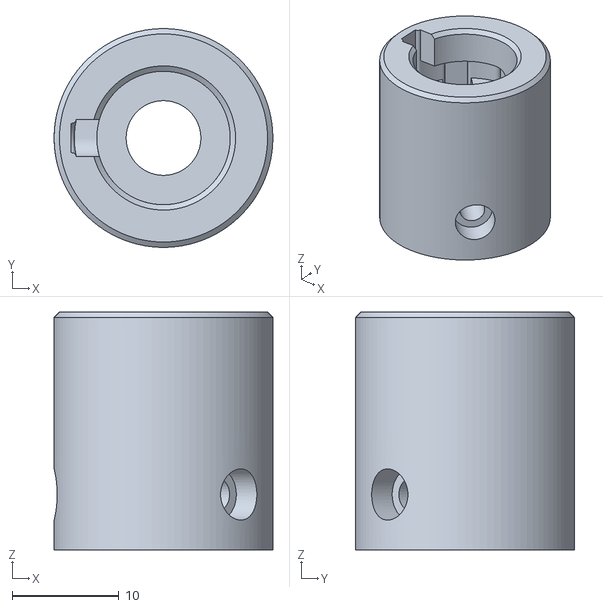
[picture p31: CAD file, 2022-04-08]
STL Files/Other/Wing fold base.stl
20.5 x 20.5 x 22.3

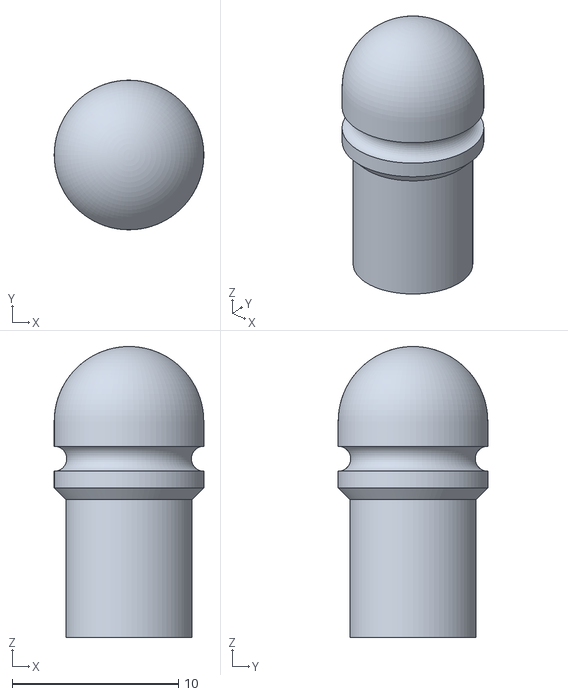
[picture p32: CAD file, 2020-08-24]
STL Files/Switches/Sw - Dome.stl
9.00 x 9.00 x 17.5

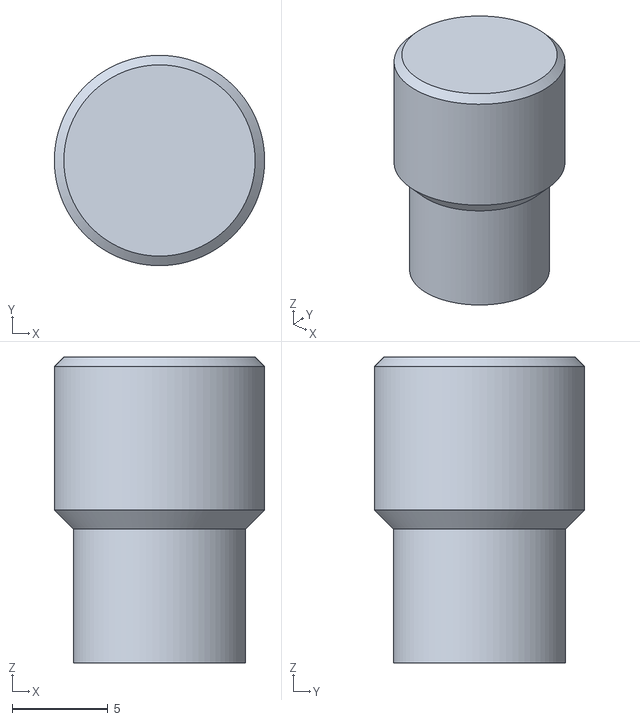
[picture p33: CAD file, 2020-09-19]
STL Files/Knobs/Tiny knob - D shaft.stl
11.0 x 11.0 x 16.0

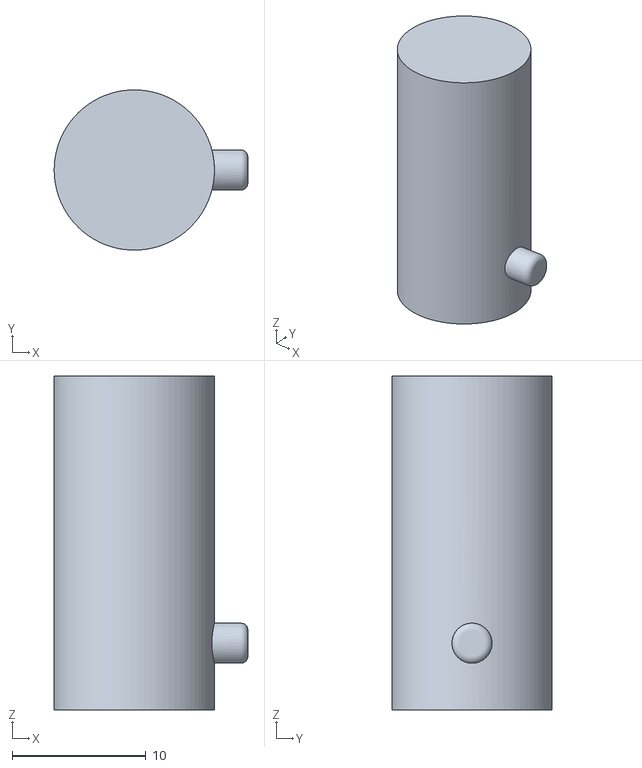
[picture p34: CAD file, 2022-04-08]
STL Files/Other/Wing fold shaft.stl
14.5 x 12.0 x 25.0

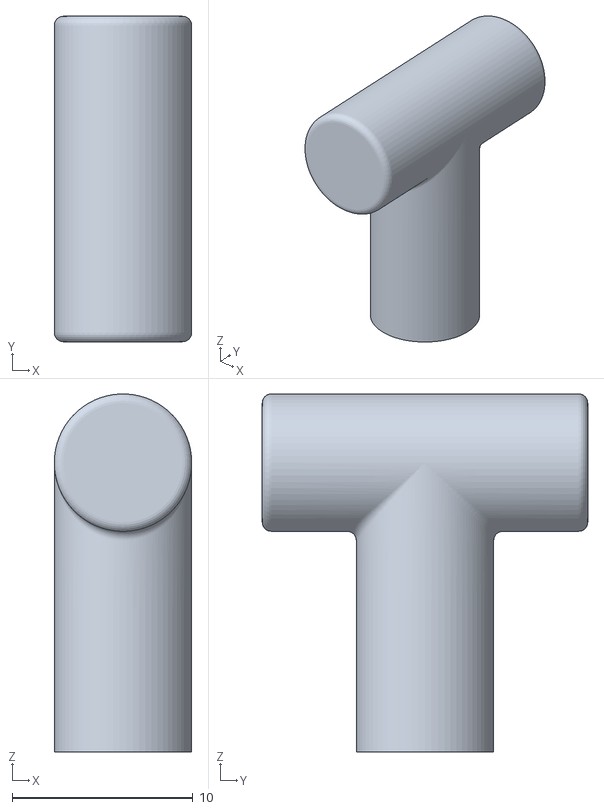
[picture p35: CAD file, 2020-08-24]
STL Files/Switches/Sw - Launch bar.stl
7.60 x 18.0 x 19.8

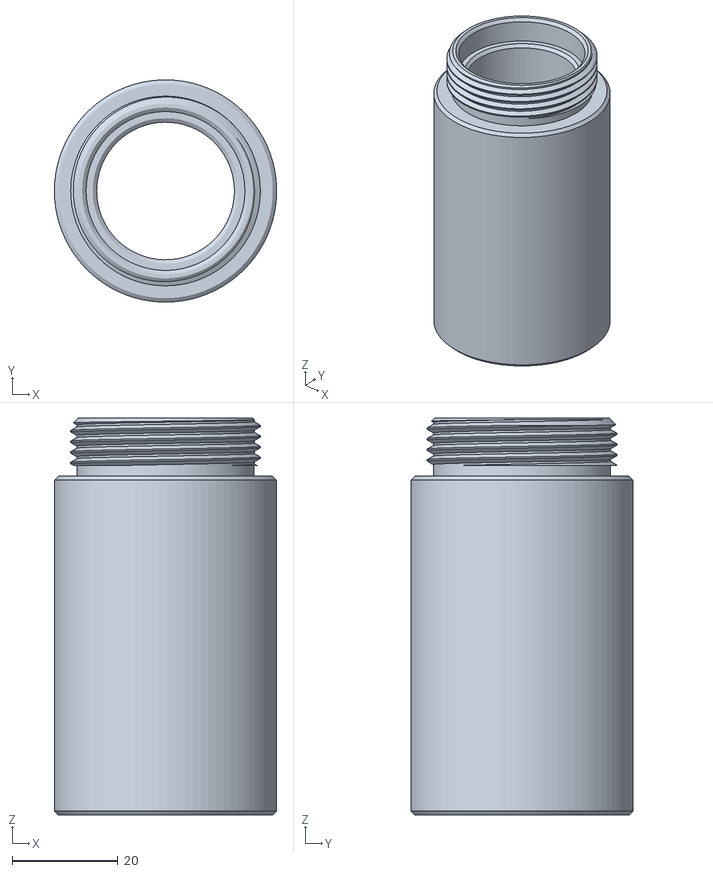
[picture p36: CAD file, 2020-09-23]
STL Files/Warthog-Virpil extensions/WH ext 75mm, 36.5.stl
42.0 x 42.0 x 75.0

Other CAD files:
DXF Files/Enclosure/MDF - Front Panel Overall Design v01.dxf
DXF Files/Enclosure/Acrylic - Front panels v01.dxf
DXF Files/Panel/Hornet Panel v15 - Fix bmp.dxf
DXF Files/Enclosure/MDF - Right console v01.dxf
STL Files/Warthog-Virpil extensions/WH ext 50mm, 37.0.stl
DXF Files/Enclosure/MDF - Front Panel Pieces v01.dxf
DXF Files/Enclosure/Acrylic - Console panels v01.dxf
DXF Files/Enclosure/Acrylic-MDF - AMPCD replacement v01.dxf
DXF Files/Enclosure/MDF - Left console v01.dxf
Fusion 360 Files/Panel - lower LG.f3d
STL Files/Knobs/Knob - Bleed air.stl
STL Files/Knobs/Knob - Cabin.stl
STL Files/Knobs/Knob - Flat sides.stl
STL Files/Knobs/Knob - Large pointy D-shaft.stl
STL Files/Knobs/Knob - Large pointy, D-shaft short.stl
STL Files/Knobs/Knob - Large pointy.stl
STL Files/Knobs/Knob - Parking brake.stl
STL Files/Knobs/Knob - Quad.stl
STL Files/Knobs/Knob - Radio tune.stl
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

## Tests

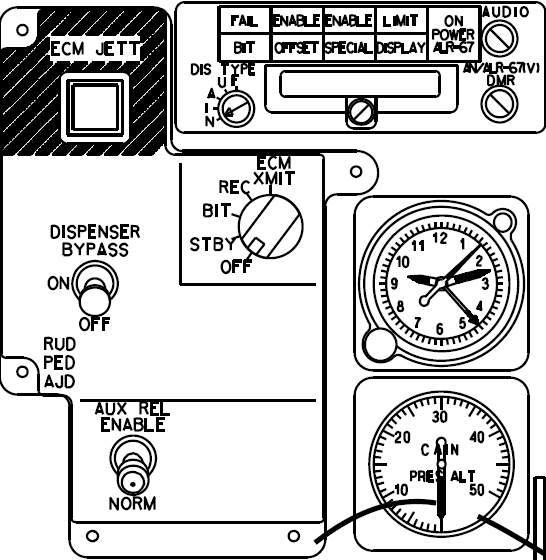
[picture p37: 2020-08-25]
DXF Files/Panel/Bitmap/Countermeasures.png

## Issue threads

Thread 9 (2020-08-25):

Fix the D-shaft knob

ColdFrontWI, 2020-08-25:
I put flat side on the wrong side of the hole relative to the set screw.  Need to rotate it.

Closed 2020-08-28.

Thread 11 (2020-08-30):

Fix the pointy D-shaft knob

ColdFrontWI, 2020-08-30:
* Expand the diameter of the hole to fit better.
* Extend the downward for short shaft on the 8-way rotary
* Lower the set screw location

ColdFrontWI, 2020-08-31:
Done.  Also corrected the intersect between the shaft and the sloped front face

Closed 2020-08-31.

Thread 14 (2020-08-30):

List of pending enhancements:

ColdFrontWI, 2020-08-30:
* Radar: Swap encoder for rotary
* INS: Swap encoder for rotary
* Jettison rotary
* Parking brake: try push/pull potentiometer
* Rewire left/right consoles, replace Bodnar with Arduino
* Countermeasures slap switch
* Controls for my seat

ColdFrontWI, 2020-09-11:
All items completed except seat controls.  Will create a separate issue for that.

Closed 2020-09-11.

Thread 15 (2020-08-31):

Update AMPCD Arduino code

ColdFrontWI, 2020-08-31:
* Previously corrected issue with jitter by requiring minimum change.
* Update code to do a 10-cycle moving average.

ColdFrontWI, 2020-09-11:
Closing this issue for the moment.  Going to try to figure out how to do this with hardware
(capacitors across the wiper / ground).

Closed 2020-09-11.

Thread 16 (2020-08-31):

Knobs/buttons to be created / printed

ColdFrontWI, 2020-08-31:
1. ~~A few special knobs~~
   * ~~Rudder trim~~
   * ~~Bleed air~~
   * ~~Cabin/suit temp~~
1. Various small round twists:
   * HUD BRT/BALANCE
   * DDI brightness / contrast
   * Vol panel, UFC, IEFE brt
   * HMD / AMPCD
1. ~~Dispense button~~
1. ~~Update Emerg Brake~~
   * ~~Add 90° limiter~~

ColdFrontWI, 2020-09-04:
Created the rudder trim knob.

ColdFrontWI, 2020-09-05:
Added bleed air and cabin/suit knobs.

ColdFrontWI, 2020-09-12:
Created parking brake mechanism

ColdFrontWI, 2020-09-13:
Created the dispense button.

Closed 2020-09-26.

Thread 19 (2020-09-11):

Correct capacitor jitter with hardware

ColdFrontWI, 2020-09-11:
Have ordered capacitors.  Going to try to wire them across the signal/ground pins of some potentiometers to remove jitter
as code does not seem to be working.

ColdFrontWI, 2020-09-13:
Spent a bit of time with this.  Seems like the sweet spot is around 1nF across the wiper/ground.  10nF is a bit noiser, as is 100pF.  680 pF may be okay too, but will likely design with 1nF.  Have a breadboard prototype ready...would probably want to make something on PCB that allows swapping capacitors (female headers on the board).

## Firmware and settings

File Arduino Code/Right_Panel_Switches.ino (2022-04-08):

#include <Joystick.h>
// #include <Rotary.h>

int i, j, k;
int NB = 1023;
int analogStep = 3;
int analogMin = 0;
int analogMax = 1023;

// Control will have:
// 6x8 button matrix (48 x 2 = 96 inputs)
// No Rotary encoders
Joystick_ JS1(
  0x03, // Address. Cannot use 0x01 or 0x02
  JOYSTICK_TYPE_JOYSTICK,
  64, // Button count
  0, // Number of hat switches
  false, // include x axis
  false, // include y axis
  false, // include z axis
  false, // include Rx axis
  false, // include Ry axis
  false, // include Rz axis
  false, // include Rudder axis
  false, // include throttle axis
  false, // include accelerator axis
  false, // include brake axis
  false // include steering axis
);

// Set up the parameters of the button matrix
const int numReads = 8; // These are the "signal" side of the switches with diodes
const int numWrites = 6; // These are the "common" side of the switches
int readPins[numReads] = {2, 3, 4, 5, 6, 7, 8, 9};  // These are the pins that will be set as inputs and be read in each cycle ("Columns")
int writePins[numWrites] = {10, 16, 14, 15, A0, A1}; // These are the pins that will be turned on/off ("Rows")

// This specifies the joystick button to be activated when each point in
// the matrix is turned on (closed switch).
int outputButton[numWrites][numReads] = {
  {49, 50, 51, 44, 45, 46, 47, 48},
  {39, 40, 41, 42, 43, 28, 34, 32},
  {37, 55, 35, NB, 29, 54, 27, 31},
  {22, 24, 26, 16, 18,  9, 11, 13},
  {52, 53, 21, 19, 14, NB, NB, NB},
  { 5,  6, NB, NB,  1, 56,  7, NB}
};

// This specifies the joystick button to be activated when each point in
// the matrix is turned off (open switch).
int outputButtonLift[numWrites][numReads] = {
  {NB, NB, NB, NB, NB, NB, NB, NB},
  {NB, NB, NB, NB, NB, NB, 33, 33},
  {38, NB, 36, NB, 30, NB, NB, 30},
  {23, 25, 25, 17, 17, 10, 12, 12},
  {NB, NB, 20, 20, 15, NB, NB, NB},
  {NB, NB, NB, NB,  0, NB,  8, NB}
};

int newButtonValue[numWrites][numReads] =
{
  {0, 0, 0, 0, 0, 0, 0, 0},
  {0, 0, 0, 0, 0, 0, 0, 0},
  {0, 0, 0, 0, 0, 0, 0, 0},
  {0, 0, 0, 0, 0, 0, 0, 0},
  {0, 0, 0, 0, 0, 0, 0, 0},
  {0, 0, 0, 0, 0, 0, 0, 0}
};
int oldButtonValue[numWrites][numReads] =
{
  {0, 0, 0, 0, 0, 0, 0, 0},
  {0, 0, 0, 0, 0, 0, 0, 0},
  {0, 0, 0, 0, 0, 0, 0, 0},
  {0, 0, 0, 0, 0, 0, 0, 0},
  {0, 0, 0, 0, 0, 0, 0, 0},
  {0, 0, 0, 0, 0, 0, 0, 0}
};

// The minimum time it has to be before the code will capture a change in a switch
// This gets reset to millis() + debounceDelay after each change in state.
long debounceTime[numWrites][numReads] = 
{
  {0, 0, 0, 0, 0, 0, 0, 0},
  {0, 0, 0, 0, 0, 0, 0, 0},
  {0, 0, 0, 0, 0, 0, 0, 0},
  {0, 0, 0, 0, 0, 0, 0, 0},
  {0, 0, 0, 0, 0, 0, 0, 0},
  {0, 0, 0, 0, 0, 0, 0, 0}
};

// How much time the code will delay between captures at each point in the matrix
int debounceDelay[numWrites][numReads] = 
{
  {50, 50, 50, 50, 50, 50, 50, 50},
  {50, 50, 50, 50, 50, 50, 50, 50},
  {50, 50, 50, 50, 50, 50, 50, 50},
  {50, 50, 50, 50, 50, 50, 50, 50},
  {50, 50, 50, 50, 50, 50, 50, 50},
  {50, 50, 50, 50, 50, 50, 50, 50}
};

// Set up stuff for the wing fold
int wingFoldPin = A3;
int wingFoldReading;
int wingFoldThresh[3][2] = {{700, 780}, {880, 940}, {1000, 1023}};
int wingFoldButtonSet[3] = {2, 3, 4};
int oldWingFoldValue = LOW, newWingFoldValue = LOW;


// Set up rotary encoders
/*
  const int numEnc = 4;
  Rotary R[numEnc] = {Rotary(0,1), Rotary(2,3), Rotary(4,5), Rotary(6,7)};  // Using the rotary library, set up pins for each
  int encDelay[numEnc] = {100, 10, 100, 100};  //How long to turn the encoder on with each press in milliseconds.  Can set unique values for each encoder.
  int encButtons[4][2] = {{1, 2}, {4, 5}, {7, 8}, {10, 11}};  // Joystick button to be sent by CW/CCW turns of each encoder
  unsigned char encResult;
*/

void setup() {
  JS1.begin();

  // Set up the input (INPUT_PULLUP) and output pins
  for (i = 0; i < numWrites; i++)
  {
    pinMode(writePins[i], OUTPUT);
    digitalWrite(writePins[i], HIGH);
  }
  for (i = 0; i < numReads; i++)
  {
    pinMode(readPins[i], INPUT_PULLUP);
  }

  // Set up the analog inputs
  // pinMode(xAxisPin, INPUT);
  // pinMode(yAxisPin, INPUT);

  delay(2500);
  // Set all the "old button" values WRONG so it has to set all the values the first time it runs the loop
  for (i = 0; i < numWrites; i++)
  {
    digitalWrite(writePins[i], LOW);
    for (j = 0; j < numReads; j++)
    {
      oldButtonValue[i][j] = digitalRead(readPins[j]);
    }
    digitalWrite(writePins[i], HIGH);
  }

  // Now run through the loop once to set the correct values and send initial button presses
  for (i = 0; i < numWrites; i++)
  {
    digitalWrite(writePins[i], LOW);
    for (j = 0; j < numReads; j++)
    {
      // Get the current value of the button, compare with previous value, and send if different
      // This is faster than sending the button value every cycle
      // Also, if a switch has been turned OFF, check to see if it has a "lift" button and activate that button
      newButtonValue[i][j] = !digitalRead(readPins[j]);
      if (newButtonValue[i][j] != oldButtonValue[i][j])
      {
        if (outputButtonLift[i][j] != NB)
        {
          if (newButtonValue[i][j] == LOW)
          {
            JS1.setButton(outputButton[i][j], LOW);
            JS1.setButton(outputButtonLift[i][j], HIGH);
          }
          else
          {
            JS1.setButton(outputButtonLift[i][j], LOW);
            JS1.setButton(outputButton[i][j], HIGH);
          }
        }
        else
          JS1.setButton(outputButton[i][j], newButtonValue[i][j]);
      }
      oldButtonValue[i][j] = newButtonValue[i][j];
    }
    digitalWrite(writePins[i], HIGH);
  }

  // Set the initial position and button value of the wing fold handle
  wingFoldReading = analogRead(wingFoldPin);
  for(i = 0; i < 3; i++)
  {
    if(wingFoldReading > wingFoldThresh[i][0] && wingFoldReading < wingFoldThresh[i][1])
      newWingFoldValue = wingFoldButtonSet[i];
  }
  if(newWingFoldValue != oldWingFoldValue)
  {
    JS1.setButton(oldWingFoldValue, LOW);
    JS1.setButton(newWingFoldValue, HIGH);
    oldWingFoldValue = newWingFoldValue;
  }

  // Need special code to check for the off value in three position toggles.
  // First the ATT/AOA switch on the HUD panel
  // THIS HAS TO BE REWRITTEN
  /*
  if(oldButtonValue[0][0] == HIGH || oldButtonValue[0][1] == HIGH)
    JS1.setButton(outputButtonLift[0][0], LOW);
  // Then the DISPENSER switch
  if(oldButtonValue[5][6] == HIGH || oldButtonValue[5][7] == HIGH)
    JS1.setButton(outputButtonLift[5][6], LOW);
  */
}

void loop() {
  // Run through the button matrix
  // Loop through the outputs checking each input as we go
  for (i = 0; i < numWrites; i++)
  {
    digitalWrite(writePins[i], LOW);
    for (j = 0; j < numReads; j++)
    {
      // Get the current value of the button, compare with previous value, and send if different
      // This is faster than sending the button value every cycle
      // Also, if a switch has been turned OFF, check to see if it has a "lift" button and activate that button
      newButtonValue[i][j] = !digitalRead(readPins[j]);
      if (newButtonValue[i][j] != oldButtonValue[i][j] && millis() > debounceTime[i][j])
      {
        debounceTime[i][j] = millis() + debounceDelay[i][j];
    		if (outputButtonLift[i][j] != NB)
          {
            if (newButtonValue[i][j] == LOW)
            {
              JS1.setButton(outputButton[i][j], LOW);
              JS1.setButton(outputButtonLift[i][j], HIGH);
            }
            else
            {
              JS1.setButton(outputButtonLift[i][j], LOW);
              JS1.setButton(outputButton[i][j], HIGH);
            }
          }
          else
            JS1.setButton(outputButton[i][j], newButtonValue[i][j]);
          // delay(debounceDelay);
      }
      oldButtonValue[i][j] = newButtonValue[i][j];

      // Since encoders are sensitive to timing, check them with every cycle
      /*
        for(k = 0; k < numEnc; k++)
        {
        encResult = R[k].process();
        if (encResult == DIR_CCW)
        {
          JS1.pressButton(encButtons[k][0]);
          delay(encDelay[k]);
          JS1.releaseButton(encButtons[k][0]);
        }
        else if (encResult == DIR_CW)
        {
          JS1.pressButton(encButtons[k][1]);
          delay(encDelay[k]);
          JS1.releaseButton(encButtons[k][1]);
        }
        }
      */
    }
    digitalWrite(writePins[i], HIGH);
  }

  // Check the position fo the wing fold handle and update if needed
  wingFoldReading = analogRead(wingFoldPin);
  for(i = 0; i < 3; i++)
  {
    if(wingFoldReading >= wingFoldThresh[i][0] && wingFoldReading <= wingFoldThresh[i][1])
      newWingFoldValue = wingFoldButtonSet[i];
  }
  if(newWingFoldValue != oldWingFoldValue)
  {
    JS1.setButton(oldWingFoldValue, LOW);
    JS1.setButton(newWingFoldValue, HIGH);
    oldWingFoldValue = newWingFoldValue;
  }
  
  // Code for analog controls
  // To avoid jitter, only change outputs when the change is > analogMin
  // If within analogMin of the min or max, force the output to the min/max
  /*
  newXValue = analogRead(xAxisPin);
  if(newXValue >= analogMax - analogStep)
  {
    JS1.setXAxis(analogMax);
    oldXValue = newXValue;
  }
  else if(newXValue <= analogMin + analogStep)
  {
    JS1.setXAxis(analogMin);
    oldXValue = newXValue;
  }
  else if(abs(newXValue - oldXValue) >= analogStep)
  {
    JS1.setXAxis(newXValue);
    oldXValue = newXValue;
  }

  newYValue = analogRead(yAxisPin);
  if(newYValue >= analogMax - analogStep)
  {
    JS1.setYAxis(analogMax);
    oldYValue = newYValue;
  }
  else if(newYValue <= analogMin + analogStep)
  {
    JS1.setYAxis(analogMin);
    oldYValue = newYValue;
  }
  else if(abs(newYValue - oldYValue) >= analogStep)
  {
    JS1.setYAxis(newYValue);
    oldYValue = newYValue;
  }
  */

}

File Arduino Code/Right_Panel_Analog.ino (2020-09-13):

#include <Joystick.h>
#include <Rotary.h>

int i, j, k;
int NB = 1023;
int analogStep = 3;
int analogMin = 0;
int analogMax = 1023;

Joystick_ JS1(
  0x03, // Address. Cannot use 0x01 or 0x02
  JOYSTICK_TYPE_JOYSTICK,
  64, // Button count
  0, // Number of hat switches
  true, // include x axis
  true, // include y axis
  true, // include z axis
  true, // include Rx axis
  true, // include Ry axis
  true, // include Rz axis
  false, // include Rudder axis
  true, // include throttle axis
  false, // include accelerator axis
  false, // include brake axis
  false // include steering axis
);


int newXValue = 0;
int oldXValue = 0;
int newYValue = 0;
int oldYValue = 0;
int newZValue = 0;
int oldZValue = 0;
int newRxValue = 0;
int oldRxValue = 0;
int newRyValue = 0;
int oldRyValue = 0;
int newRzValue = 0;
int oldRzValue = 0;
int newThrottleValue = 0;
int oldThrottleValue = 0;


// Set up rotary encoders
  const int numEnc = 3;
  Rotary R[numEnc] = {Rotary(2,3), Rotary(10,16), Rotary(14,15)};  // Using the rotary library, set up pins for each
  int encDelay[numEnc] = {20, 20, 20};  //How long to turn the encoder on with each press in milliseconds.  Can set unique values for each encoder.
  int encButtons[4][2] = {{0, 1}, {4, 5}, {2, 3}};  // Joystick button to be sent by CW/CCW turns of each encoder
  unsigned char encResult;

// Set up the input pins for the axes
int xAxisPin = A0;
int yAxisPin = A1;
int zAxisPin = A2;
int RxAxisPin = A3;
int RyAxisPin = A6;
int RzAxisPin = A7;
int ThrottlePin = A8;


void setup() {
  JS1.begin();


  // Set up the input (INPUT_PULLUP) and output pins
  /* 
  for (i = 0; i < numWrites; i++)
  {
    pinMode(writePins[i], OUTPUT);
    digitalWrite(writePins[i], HIGH);
  }
  for (i = 0; i < numReads; i++)
  {
    pinMode(readPins[i], INPUT_PULLUP);
  }
  */
  
  // Set up the analog inputs
  pinMode(xAxisPin, INPUT);
  pinMode(yAxisPin, INPUT);
  pinMode(zAxisPin, INPUT);
  pinMode(RxAxisPin, INPUT);
  pinMode(RyAxisPin, INPUT);
  pinMode(RzAxisPin, INPUT);
  pinMode(ThrottlePin, INPUT);

  delay(2500);
  
}

void loop() {
// Since encoders are sensitive to timing, check them with every cycle
  for(k = 0; k < numEnc; k++)
  {
    encResult = R[k].process();
    if (encResult == DIR_CCW)
    {
      JS1.pressButton(encButtons[k][0]);
      delay(encDelay[k]);
      JS1.releaseButton(encButtons[k][0]);
    }
    else if (encResult == DIR_CW)
    {
      JS1.pressButton(encButtons[k][1]);
      delay(encDelay[k]);
      JS1.releaseButton(encButtons[k][1]);
    }
  }
  
  // Code for analog controls
  // To avoid jitter, only change outputs when the change is > analogMin
  // If within analogMin of the min or max, force the output to the min/max
  newXValue = analogRead(xAxisPin);
  if(newXValue != oldXValue)
  {
    JS1.setXAxis(newXValue);
    oldXValue = newXValue;
  }

  newYValue = analogRead(yAxisPin);
  if(newYValue != oldYValue)
  {
    JS1.setYAxis(newYValue);
    oldYValue = newYValue;
  }

  newZValue = analogRead(zAxisPin);
  if(newZValue != oldZValue)
  {
    JS1.setZAxis(newZValue);
    oldZValue = newZValue;
  }

  newRxValue = analogRead(RxAxisPin);
  if(newRxValue != oldRxValue)
  {
    JS1.setRxAxis(newRxValue);
    oldRxValue = newRxValue;
  }
 
  newRyValue = analogRead(RyAxisPin);
  if(newRyValue != oldRyValue)
  {
    JS1.setRyAxis(newRyValue);
    oldRyValue = newRyValue;
  }

  newRzValue = analogRead(RzAxisPin);
  if(newRzValue != oldRzValue)
  {
    JS1.setRzAxis(newRzValue);
    oldRzValue = newRzValue;
  }

  newThrottleValue = analogRead(ThrottlePin);
  if(newThrottleValue != oldThrottleValue)
  {
    JS1.setThrottle(newThrottleValue);
    oldThrottleValue = newThrottleValue;
  }


}

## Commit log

2020-08-24 First batch of cockpit knobs
    STL files created in Fusion 360
    [Knob - Flat sides.stl, Knob - Large pointy D-shaft.stl, Knob - Large pointy.stl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]
2020-08-25 Update and rename STL.txt to Readme.md
2020-08-28 Rename 05_Hornet_AMPCD_CMS.ino to Arduino Code/05_Hornet_AMPCD_CMS.ino
2020-08-30 Updated .gitignore
    [Button adapter.stl, Multiselector gear 18t.stl, Panel - lower LG.stl]
2020-08-31 Updates to the "Large Pointy" knobs
    These are the ones used for the INS and the Radar.
    * Added a new version to fit a shorter shaft rotary switch
    * Shortened the shaft depth on the other two increase distance from front face to prevent printing anomalies
    [Knob - Large pointy D-shaft.stl, Knob - Large pointy, D-shaft short.stl, Knob - Large pointy.stl]
2020-08-31 Fix Large pointy D-shaft
    Had not increased diameter in last version.
    [Knob - Large pointy D-shaft.stl]
2020-08-31 Delete Knob - Large pointy, D-shaft short.gcode
    Loaded the wrong file...
2020-08-31 Changes identified when setting up github
    [Knob - Large pointy D-shaft.stl, Knob - Large pointy, D-shaft short.stl, Knob - Large pointy.stl]
2020-09-04 Create Knob - Rudder trim.stl
    [Knob - Rudder trim.stl]
2020-09-05 Added bleed air and cabin/suit knobs
    [Knob - Bleed air.stl, Knob - Cabin.stl, Knob - Suit.stl]
2020-09-13 Added some new pictures and STL files
    [Dispense button.stl, Hand brake base.stl, Hand brake shaft.stl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]
2020-09-13 Update STL/Other readme
2020-09-13 Added updated arduino code for left and right consoles.
2020-09-19 Updated STL files
    Added several small volume knobs as well as knobs for the EWR unit. Also created a stick extension.
    [50mm WH extension.stl, Small knurled knob.stl, Small volume knob.stl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]
2020-09-20 Warthog extension update
    [100mm WH extension.stl, 25mm WH extension.stl, 50mm WH extension.stl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]
2020-09-23 Created dedicated folder for Warthog/Virpil extensions
    [WH ext 100mm, 36.0.stl, WH ext 100mm, 36.5.stl, WH ext 100mm, 37.0.stl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]
2020-10-18 Create Panel - lower LG.f3d
    [Panel - lower LG.f3d]
2022-04-08 Upload wing fold handle
    [Hornet Panel v14 - New CMS buttons.dxf, Hornet Panel v15 - Fix bmp.dxf, Wing fold base.stl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]
2022-04-08 Update Arduino code with links.
